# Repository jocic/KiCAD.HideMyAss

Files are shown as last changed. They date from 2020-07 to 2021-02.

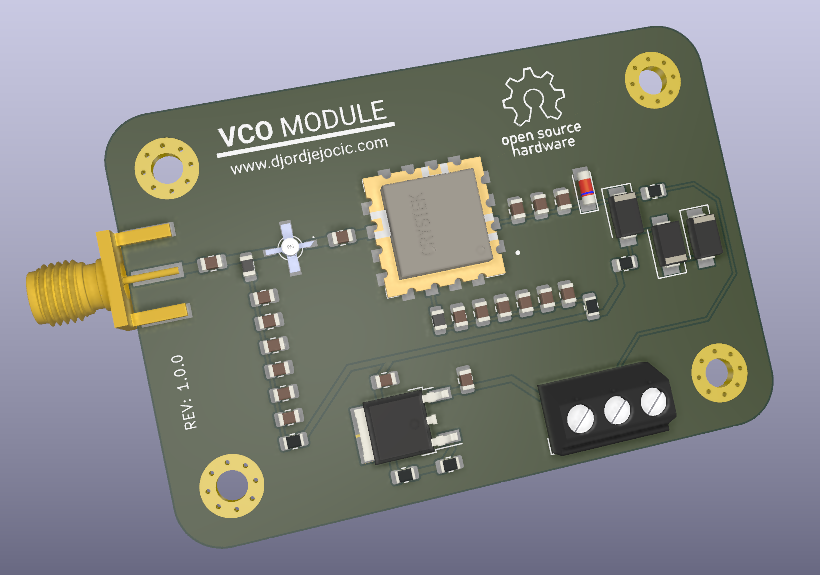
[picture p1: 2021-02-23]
hardware-modular/vco-variants/cvco-general/assets/rendering.png

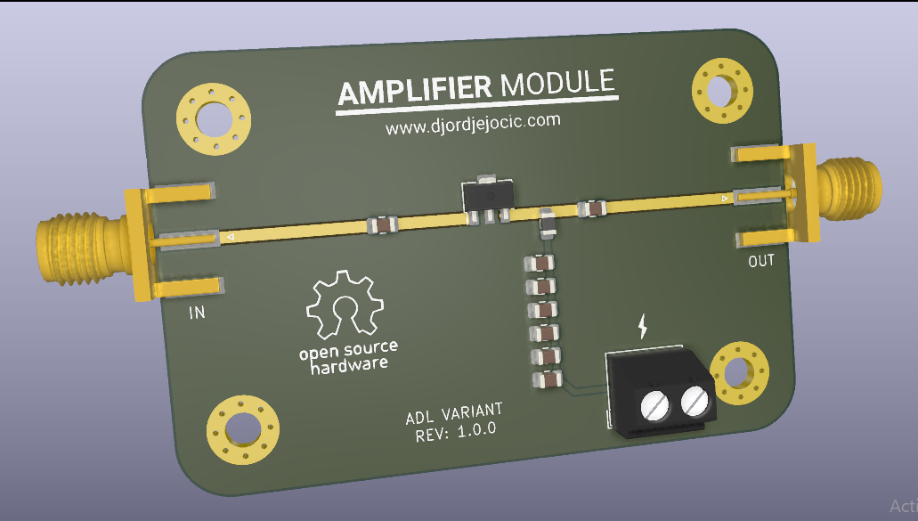
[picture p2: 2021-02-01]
hardware-modular/amplifiers/adl-variant/assets/rendering.png

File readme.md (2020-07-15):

# HideMyAss

**Song of the project:** [Judas Priest - Breaking The Law](https://www.youtube.com/watch?v=L397TWLwrUU)

*  LoJack (173 MHz)
*  SM (925 – 960 MHz)
*  DCS (1805 – 1880 MHz)
*  3G (2100 – 2170 MHz )
*  4G Low (790 – 870 MHz)
*  4G High (2600 – 2690 MHz)
*  5G F1 (450 MHz to 6 GHz)
*  5G F2 (24.25 GHz to 52.6 GHz)
*  WiFi (2400 – 2500 MHz)
*  GPS L1 (1570 – 1580 MHz)
*  GPS L2 (1220 – 1230 MHz)
*  Bluetooth (2.402 GHz - 2.480 GHz)

When finished, device can be ordered directly from my website.

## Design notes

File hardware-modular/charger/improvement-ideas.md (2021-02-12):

- Serial IO port for AT commands (start charging, stop charging, charging status, pause charging, current control, etc.)
- Replace LM741 with a proper comparator
- Use %1 5V voltage reference for the ADC
- Add a boost converter for battery bank that can be used on laptops
- Increase the current up to 1A
- Experiment with LM317 & 0.1A precision voltage regulator for creating precise voltage references ex. 4.2V for the shut off, and 5 for ADC
- Design or find enclosure for the battery bank

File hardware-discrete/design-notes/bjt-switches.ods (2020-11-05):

Device | BD137 |  | Ic | 0.45 | A
Vcc | 7.4 | V | Ib | 0.03 | A
Vbb | 3.5 | V | Rc | 15.33 | Ohm
Vsat | 0.5 | V | Pc | 3.33 | W
Vbe | 1 | V | Rb | 100.00 | Ohm
HFEmin | 25 |  | Pb | 0.09 | W
 |  |  | HFE | 18.00
Topology | Basic |  | Saturated | Yes
Device | 2N3904 |  | Ic | 0.20 | A
Vcc | 7.4 | V | Ib | 0.03 | A
Vbb | 3.5 | V | Rc | 35.50 | Ohm
 |  |  | Pc | 1.48 | W
Vsat | 0.3 | V | Rb | 100.00 | Ohm
 |  |  | Pb | 0.10 | W
Vbe | 0.65 | V | HFE | 7.02
HFEmin | 15 | V
Topology | Basic |  | Saturated | Yes
 |  |  |  |  |  | Basic Topology

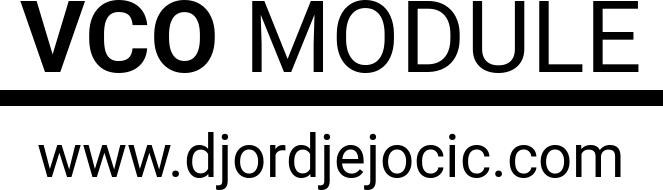
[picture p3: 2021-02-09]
hardware-modular/vco-variants/cvco-general/assets/label.png

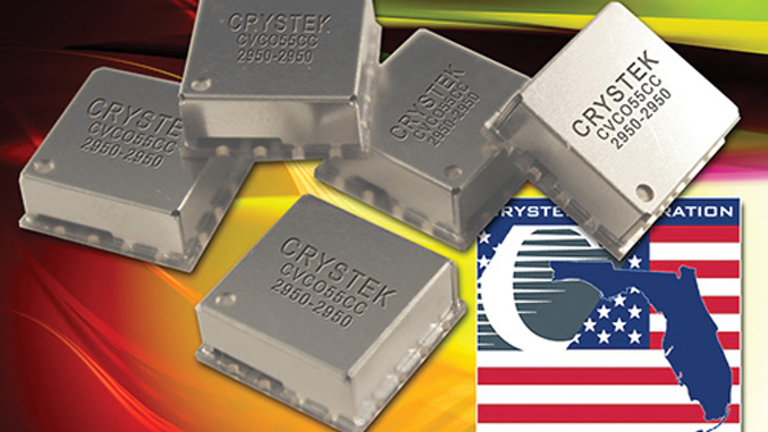
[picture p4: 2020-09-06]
other/datasheet/mwrf_1283_crystek_0.png

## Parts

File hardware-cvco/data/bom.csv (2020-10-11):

Reference | Quantity | Value | Footprint | Datasheet | LCSC Part # | Mouser Part #
BT1 | 1 | 3.7V | CVCO:2-2.54mm-Horizontal-Molex | ~ | C132504
C1 C3 C5 C7 C27 C29 C31 C14 C16 C18 C20 C41 C39 C37 C44 C56 | 16 | 1nF | Capacitor_SMD:C_0805_2012Metric_Pad1.15x1.40mm_HandSolder | ~ | C1791
C10 | 1 | 220pF | Capacitor_SMD:C_0805_2012Metric_Pad1.15x1.40mm_HandSolder | ~ | C1727
C11 | 1 | 100pF | Capacitor_SMD:C_0805_2012Metric_Pad1.15x1.40mm_HandSolder | ~ | C1790
C12 C54 | 2 | 47pF | Capacitor_SMD:C_0805_2012Metric_Pad1.15x1.40mm_HandSolder | ~ | C107118
C13 C22 | 2 | 0.1uF | Capacitor_SMD:C_0805_2012Metric_Pad1.15x1.40mm_HandSolder | ~ | C62912
C2 C4 C6 C8 C28 C30 C32 C15 C17 C19 C21 C42 C40 C38 | 14 | 0.1nF | Capacitor_SMD:C_0805_2012Metric_Pad1.15x1.40mm_HandSolder | ~ | C159771
C33 | 1 | 33pF | Capacitor_SMD:C_0805_2012Metric_Pad1.15x1.40mm_HandSolder | ~ | C157687
C34 | 1 | 27pF | Capacitor_SMD:C_0805_2012Metric_Pad1.15x1.40mm_HandSolder | ~ | C8031
C35 | 1 | 22pF | Capacitor_SMD:C_0805_2012Metric_Pad1.15x1.40mm_HandSolder | ~ | C24658
C43 C36 | 2 | 4.7μF | Capacitor_SMD:C_0805_2012Metric_Pad1.15x1.40mm_HandSolder | ~ | C37818
C51 C24 C50 C48 C26 | 5 | 0.1μF | Capacitor_SMD:C_0805_2012Metric_Pad1.15x1.40mm_HandSolder | ~ | C38141
C52 C53 C49 C23 C47 C46 C45 C25 | 8 | 1μF | Capacitor_SMD:C_0805_2012Metric_Pad1.15x1.40mm_HandSolder | ~ | C215803
C57 C58 C55 | 3 | 10μF | Capacitor_SMD:C_0805_2012Metric_Pad1.15x1.40mm_HandSolder | ~ | C40894
C9 | 1 | 470pF | Capacitor_SMD:C_0805_2012Metric_Pad1.15x1.40mm_HandSolder | ~ | C1743
D1 | 1 | 5.1V | Diode_SMD:D_MiniMELF | ~ | C305343
D10 D12 | 2 | 10V | Diode_SMD:D_MiniMELF | ~ | C398894
D11 | 1 | 1N4002 | Diode_SMD:D_SMA_Handsoldering | ~ | C433393
D3 D2 | 2 | 18V | Diode_SMD:D_MiniMELF | ~ | C268731
D6 | 1 | 16V | Diode_SMD:D_MiniMELF | ~ | C313481
D7 D5 D4 | 3 | 20V | Diode_SMD:D_MiniMELF | ~ | C398899
D8 | 1 | Green | CVCO:2-2.54mm-Horizontal-Molex | ~ | C99763
D9 | 1 | Orange | CVCO:2-2.54mm-Horizontal-Molex | ~ | C99759
F1 | 1 | 1.5A Fast | Fuse:Fuse_1206_3216Metric_Pad1.42x1.75mm_HandSolder | ~ | C151143
J3 J4 J5 J6 J1 J2 J7 | 7 | SMA | CVCO:SMA-Edge | ~ | C530661
J8 | 1 | Pickit 2 | Connector_PinSocket_2.54mm:PinSocket_1x03_P2.54mm_Horizontal | ~ | C49257
J9 | 1 | DC | Connector_Wire:SolderWirePad_1x02_P3.81mm_Drill1mm | ~
L1 | 1 | 10μH | Capacitor_SMD:C_0805_2012Metric_Pad1.15x1.40mm_HandSolder | ~ | C1046
Q1 | 1 | AOD403 | Package_TO_SOT_SMD:TO-252-2 | https://datasheet.lcsc.com/szlcsc/1811071514_Alpha-Omega-Semicon-AOD403_C28969.pdf | C28969
Q2 | 1 | MBT2222 | Package_TO_SOT_SMD:SOT-23 | https://datasheet.lcsc.com/szlcsc/1809272022_ON-Semiconductor-MMBT2222ALT1G_C82460.pdf | C82460
R1 R17 R35 R9 R6 R21 R20 R19 R4 R7 R3 R2 R10 R11 R12 R25 R26 R27 | 18 | 1k | Resistor_SMD:R_0805_2012Metric_Pad1.15x1.40mm_HandSolder | ~ | C17513
R13 R28 | 2 | 220 | Resistor_SMD:R_0805_2012Metric_Pad1.15x1.40mm_HandSolder |  | C17557
R14 | 1 | 560 | Resistor_SMD:R_0805_2012Metric_Pad1.15x1.40mm_HandSolder |  | C28636
R16 R30 | 2 | 470 | Resistor_SMD:R_0805_2012Metric_Pad1.15x1.40mm_HandSolder |  | C17710
R18 R39 R23 R54 R53 | 5 | 2k | Resistor_SMD:R_0805_2012Metric_Pad1.15x1.40mm_HandSolder | ~ | C17604
R24 R8 | 2 | 1.4k | Resistor_SMD:R_0805_2012Metric_Pad1.15x1.40mm_HandSolder | ~ | C17388
R29 | 1 | 270 | Resistor_SMD:R_0805_2012Metric_Pad1.15x1.40mm_HandSolder |  | C17590
R31 | 1 | 3M | Resistor_SMD:R_0805_2012Metric_Pad1.15x1.40mm_HandSolder | ~ | C17662
R34 R15 | 2 | 680 | Resistor_SMD:R_0805_2012Metric_Pad1.15x1.40mm_HandSolder | ~ | C17798
R36 R33 | 2 | 120 | Resistor_SMD:R_0805_2012Metric_Pad1.15x1.40mm_HandSolder | ~ | C111022
R40 | 1 | 3.3k | Resistor_SMD:R_0805_2012Metric_Pad1.15x1.40mm_HandSolder | ~ | C26010
R41 R51 R52 | 3 | 15k | Resistor_SMD:R_0805_2012Metric_Pad1.15x1.40mm_HandSolder | ~ | C17475
R42 R37 | 2 | 4.7k | Resistor_SMD:R_0805_2012Metric_Pad1.15x1.40mm_HandSolder | ~ | C47010
R44 | 1 | 27k | Resistor_SMD:R_0805_2012Metric_Pad1.15x1.40mm_HandSolder | ~ | C17593
R45 | 1 | 6.8k | Resistor_SMD:R_0805_2012Metric_Pad1.15x1.40mm_HandSolder | ~ | C17772
R48 R32 R43 | 3 | 100k | Resistor_SMD:R_0805_2012Metric_Pad1.15x1.40mm_HandSolder | ~ | C55868
R49 R46 R38 R47 | 4 | 10k | Resistor_SMD:R_0805_2012Metric_Pad1.15x1.40mm_HandSolder | ~ | C55866
R5 R22 | 2 | 3.9k | Resistor_SMD:R_0805_2012Metric_Pad1.15x1.40mm_HandSolder | ~ | C17614
R50 | 1 | 10 | Resistor_SMD:R_0805_2012Metric_Pad1.15x1.40mm_HandSolder | ~
R55 | 1 | 150 | Resistor_SMD:R_0805_2012Metric_Pad1.15x1.40mm_HandSolder | ~ | C17513
R56 | 1 | 480 | Resistor_SMD:R_0805_2012Metric_Pad1.15x1.40mm_HandSolder | ~ | C55866
R57 | 1 | 100 | Resistor_SMD:R_0805_2012Metric_Pad1.15x1.40mm_HandSolder | ~ | C17513
SW1 | 1 | On/Off | CVCO:2-2.54mm-Horizontal-Molex |  | C505003
TH1 | 1 | 10k | CVCO:2-2.54mm-Horizontal-Molex | ~ | C13879
U1 | 1 | 74LS07 | Package_SO:SOIC-14_3.9x8.7mm_P1.27mm | http://www.ti.com/lit/gpn/sn74LS06 | C513513
U10 | 1 | TPS61046 | Package_TO_SOT_SMD:SOT-23-6_Handsoldering | https://datasheet.lcsc.com/szlcsc/2001152032_Texas-Instruments-TLV61046ADBVR_C464815.pdf | C464815
U11 | 1 | BQ21040 | Package_TO_SOT_SMD:SOT-23-6 | https://datasheet.lcsc.com/szlcsc/1810101925_Texas-Instruments-BQ21040DBVR_C202311.pdf | C202311
U12 | 1 | LM324 | Package_SO:SOIC-14_3.9x8.7mm_P1.27mm | http://www.ti.com/lit/ds/symlink/lm2902-n.pdf | C71035
U13 | 1 | LM317DCYR | Package_TO_SOT_SMD:SOT-223-3_TabPin2 | https://datasheet.lcsc.com/szlcsc/1811032110_Texas-Instruments-LM317DCYR_C51466.pdf | C51466
U14 | 1 | LM386 | Package_SO:SO-8_5.3x6.2mm_P1.27mm | http://www.ti.com/lit/ds/symlink/lm386.pdf
U4 U5 U7 U8 U2 U3 U9 | 7 | NLB-310-T1 | CVCO:Micro-X-4 |  |  | 772-NLB-310
U6 | 1 | PIC12F675-ISN | Package_SO:SOIC-8_3.9x4.9mm_P1.27mm | http://ww1.microchip.com/downloads/en/DeviceDoc/41190G.pdf | C96100
Y1 | 1 | CVCO55CW-0100-0200 | CVCO:CVCO55 | https://www.crystek.com/microwave/admin/webapps/welcome/files/vco/CVCO55CW-0100-0200.pdf |  | 549-CV55CW0100-0200
Y2 | 1 | CVCO55CW-0200-0500 | CVCO:CVCO55 | https://www.crystek.com/microwave/admin/webapps/welcome/files/vco/CVCO55CW-0200-0500.pdf |  | 549-CV55CW0200-0500
Y3 | 1 | CV55CW500-1000 | CVCO:CVCO55 | https://www.crystek.com/microwave/admin/webapps/welcome/files/vco/CVCO55CW-0500-1000.pdf |  | 549-CV55CW500-1000
Y4 | 1 | CVCO55CW-1000-2000 | CVCO:CVCO55 | https://www.crystek.com/microwave/admin/webapps/welcome/files/vco/CVCO55CW-1000-2000.pdf |  | 549-CV55CW1000-2000
Y5 | 1 | CV55BE1600-3200 | CVCO:CVCO55 | https://www.crystek.com/microwave/admin/webapps/welcome/files/vco/CVCO55CW-1600-3200.pdf |  | 549-CV55BE1600-3200
Y6 | 1 | CVCO55CC-3180-3710 | CVCO:CVCO55 | https://www.crystek.com/microwave/admin/webapps/welcome/files/vco/CVCO55CC-3180-3710.pdf |  | 549-CVCO55CC31803710
Y7 | 1 | CVCO55CW-3500-4500 | CVCO:CVCO55 | https://www.crystek.com/microwave/admin/webapps/welcome/files/vco/CVCO55CW-3500-4500.pdf |  | 549-CVC55CW3500-4500

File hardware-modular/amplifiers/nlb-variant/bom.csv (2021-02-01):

Reference | Quantity | Value | Footprint | Datasheet
C1 C2 | 2 | 1μF | Capacitor_SMD:C_0805_2012Metric | ~
C3 C4 | 2 | 1.2nF | Capacitor_SMD:C_0805_2012Metric | ~
C5 C6 | 2 | 68pF | Capacitor_SMD:C_0805_2012Metric | ~
C7 C8 | 2 | 0.1μF | Capacitor_SMD:C_0805_2012Metric | ~
H1 H2 H3 H4 | 4 | Mounting Pad | MountingHole:MountingHole_3.2mm_M3_Pad_Via | ~
J1 | 1 | DC_IN | TerminalBlock_4Ucon:TerminalBlock_4Ucon_1x02_P3.50mm_Horizontal | ~
J2 | 1 | RF_IN | Connector_Coaxial:SMA_Amphenol_132289_EdgeMount | ~
J3 | 1 | RF_OUT | Connector_Coaxial:SMA_Amphenol_132289_EdgeMount | ~
L1 | 1 | 470μH | Inductor_SMD:L_0805_2012Metric | ~
R1 | 1 | 300 | Resistor_SMD:R_0805_2012Metric | ~
U1 | 1 | NLB-310 | CVCO:Micro-X-4

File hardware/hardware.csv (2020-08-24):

Value | Footprint | Designator | Quantity | LCSC Part #
USBLC6-2 | SOT-23-6 | U3 | 1 | C7519
PIC18F45K50_QFP | TQFP-44 | U5 | 1 | C219580
100nF | 0603 | C3 | 1 | C14663
LM317A | TO-252-2 | U4 | 1 | C75510
0.1μF | 0603 | C5 | 1 | C14663
1μF | 0603 | C13 | 1 | C15849
1k | 0603 | R7 | 1 | C21190
1.5k | 0603 | R8 | 1 | C22843
M7 | Diotec | D4 | 1 | C95872
10μF | 0603 | C12 | 1 | C19702
DW01+G | TSOT-23-6 | U1 | 1 | C14213
100 | 0603 | R4 | 1 | C7250
0.1μF | 0603 | C4 | 1 | C14663
TP4056 | SSOP-8_2 | U2 | 1 | C16581
FS8205 | TSOT-23-6 | Q1 | 1 | C32254
1k | 0603 | R6 | 1 | C21190
180 | 0603 | R1 | 1 | C25810
ZMM5V1 | MiniMELF | D2 | 1 | C8061
GHC-YR | 0603 | D1 | 1 | C72043
BHC-ZL | 0603 | D3 | 1 | C72041
68 | 0603 | R2 | 1 | C13415
68 | 0603 | R3 | 1 | C13415
10μF | 0603 | C1 | 1 | C19702
2k | 0603 | R5 | 1 | C22975
10μF | 0603 | C2 | 1 | C19702
10μF | 0603 | C6 | 1 | C19702
0.1μF | 0603 | C7 | 1 | C14663
0.1μF | 0603 | C8 | 1 | C14663
10μF | 0603 | C11 | 1 | C19702
0.1μF | 0603 | C10 | 1 | C14663
0.1μF | 0603 | C9 | 1 | C14663
480 | 0603 | R10 | 1 | C17480
10k | 0603 | R9 | 1 | C25804
0.1μF | 0603 | C14 | 1 | C14663

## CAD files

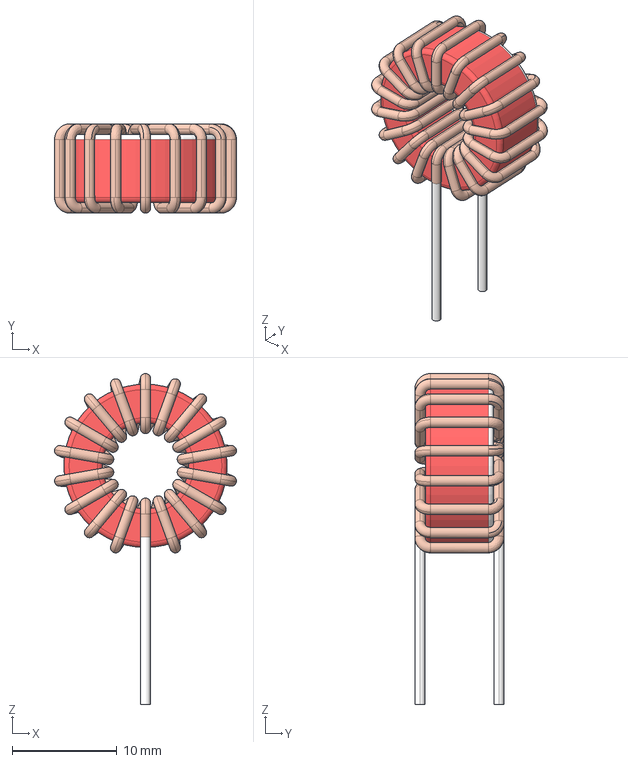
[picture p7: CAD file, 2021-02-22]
other/3d-models/toroidal-horizontal.step
17.4 x 8.54 x 31.6 mm

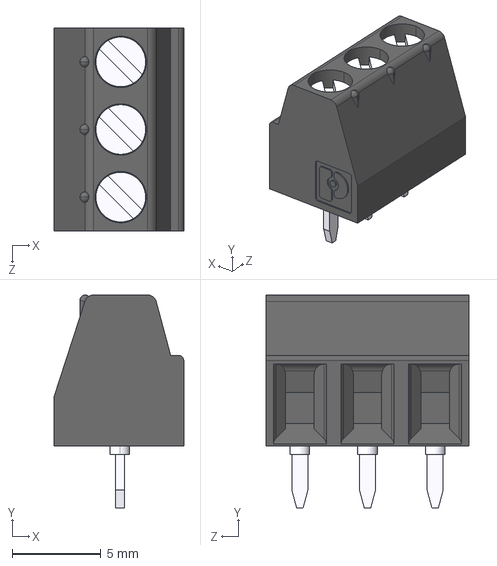
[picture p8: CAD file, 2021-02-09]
other/3d-models/3-3.84-terminal-block.step
7.30 x 12.0 x 11.4 mm

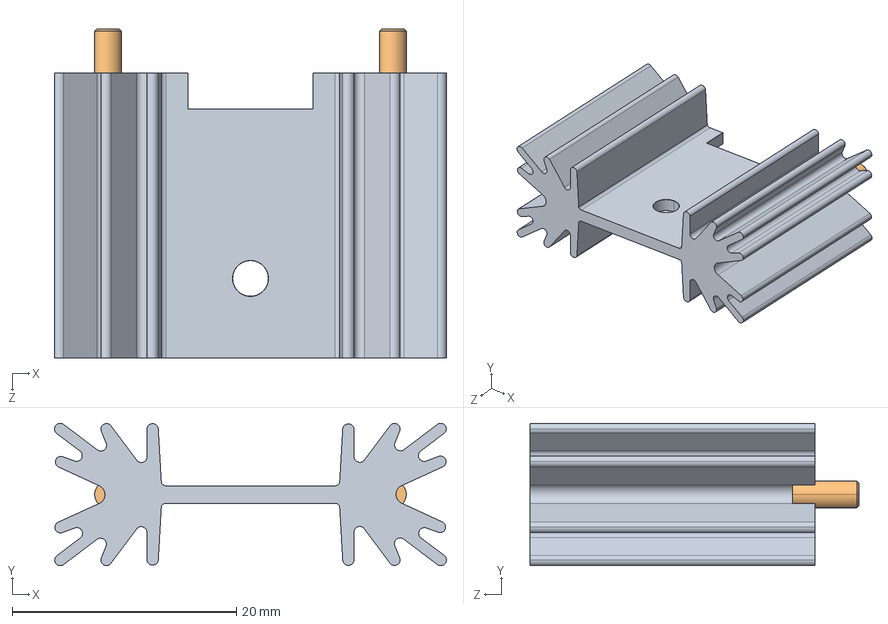
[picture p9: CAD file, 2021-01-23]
other/3d-models/to-220-heatsink.step
34.9 x 12.7 x 29.4 mm

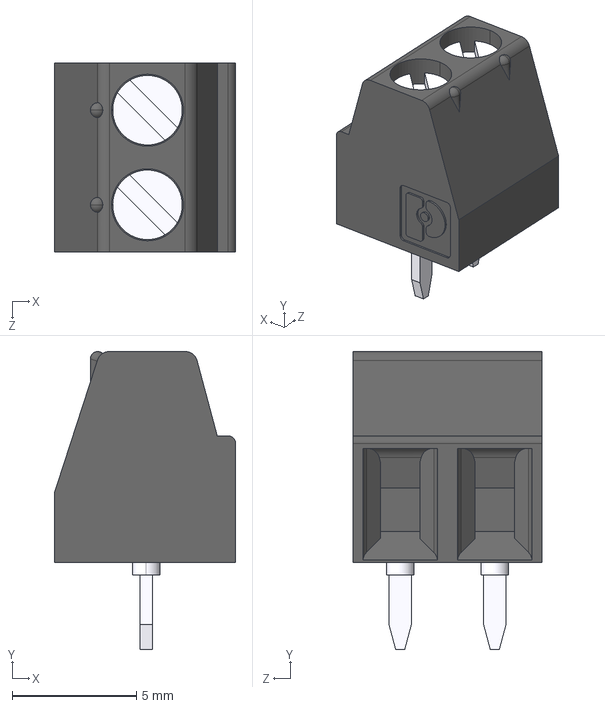
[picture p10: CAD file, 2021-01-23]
other/3d-models/2-3.84-terminal-block.step
7.30 x 12.0 x 7.62 mm

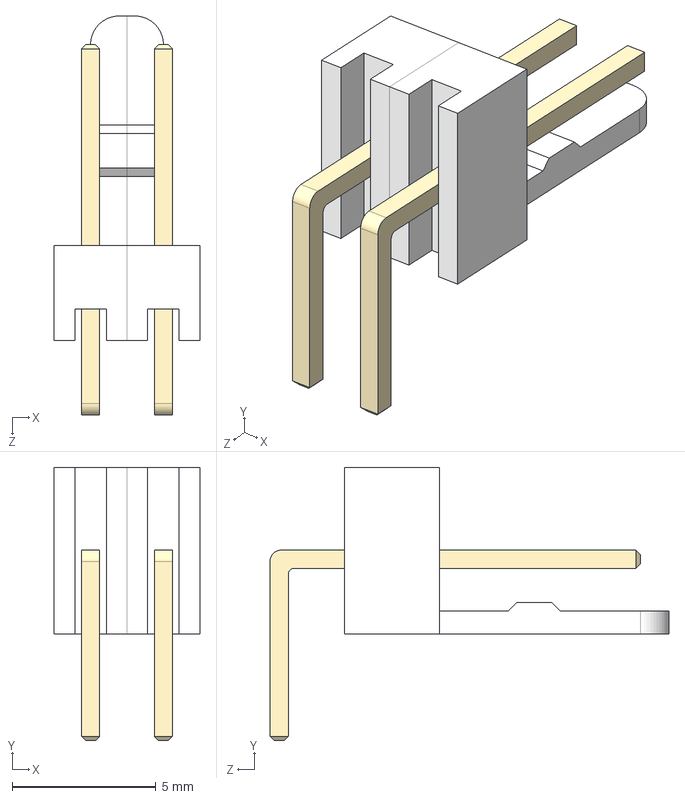
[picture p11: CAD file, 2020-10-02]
other/3d-models/2-2.54mm-horizontal-molex.step
5.08 x 9.52 x 13.9 mm
Molex_Stecker_90Grad_rechts
Molex_Stecker_90Grad_links

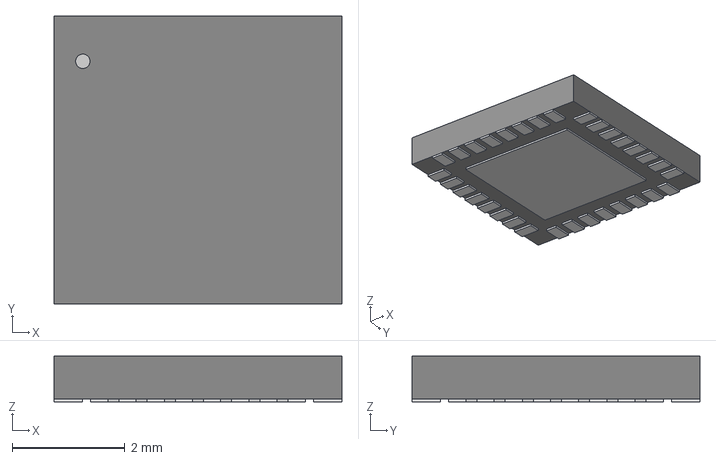
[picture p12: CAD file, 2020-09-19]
other/3d-models/tqfn-32.step
5.11 x 5.11 x 0.815 mm

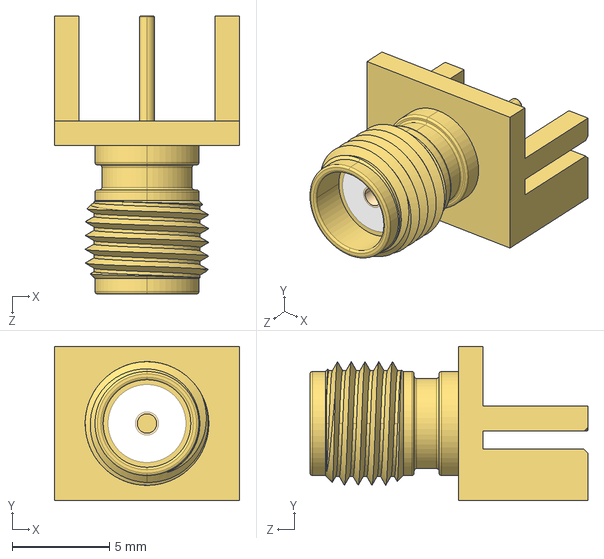
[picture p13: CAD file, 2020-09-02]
other/3d-models/sma-edge.step
9.52 x 7.92 x 14.3 mm

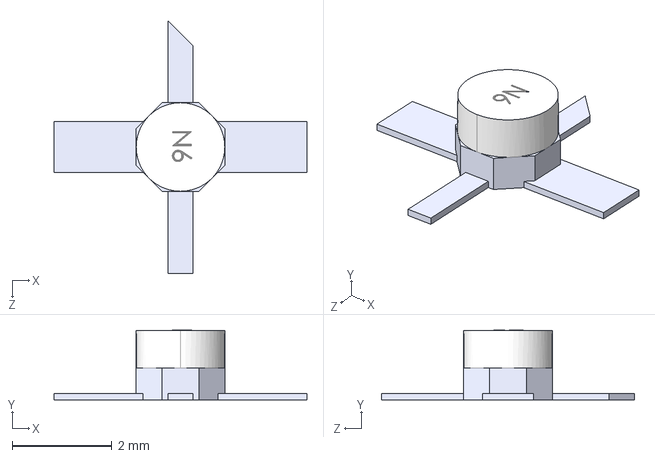
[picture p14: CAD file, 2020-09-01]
other/3d-models/micro-x-4.step
5.08 x 1.40 x 5.08 mm

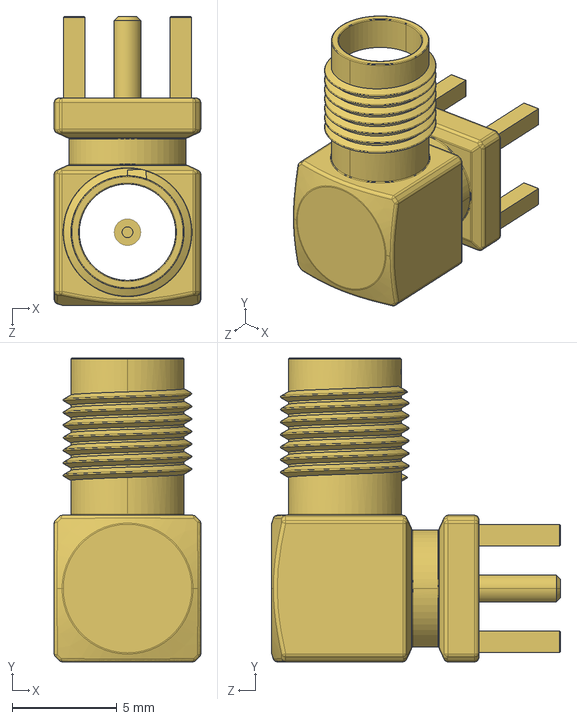
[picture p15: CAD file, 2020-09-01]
other/3d-models/sma-angled.step
7.00 x 14.5 x 13.8 mm

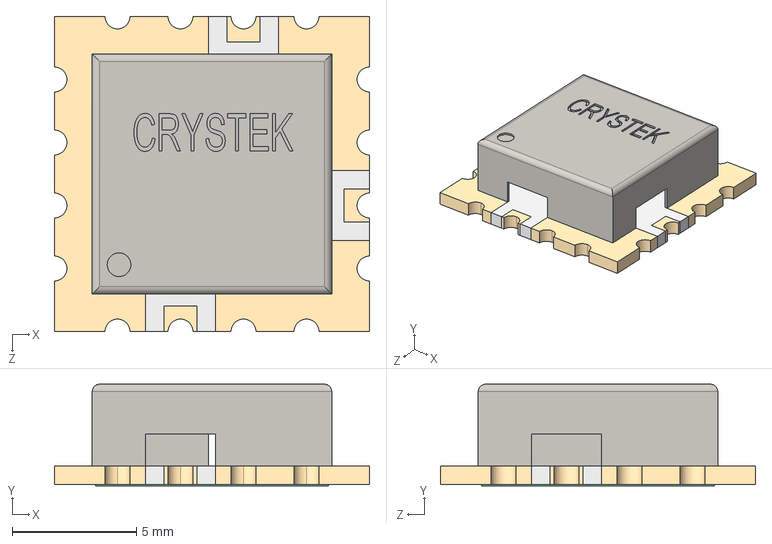
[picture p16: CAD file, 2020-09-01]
other/3d-models/cvco55.step
12.7 x 4.10 x 12.7 mm

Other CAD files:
software-discrete/dist/main.obj
software-discrete/dist/startup.obj

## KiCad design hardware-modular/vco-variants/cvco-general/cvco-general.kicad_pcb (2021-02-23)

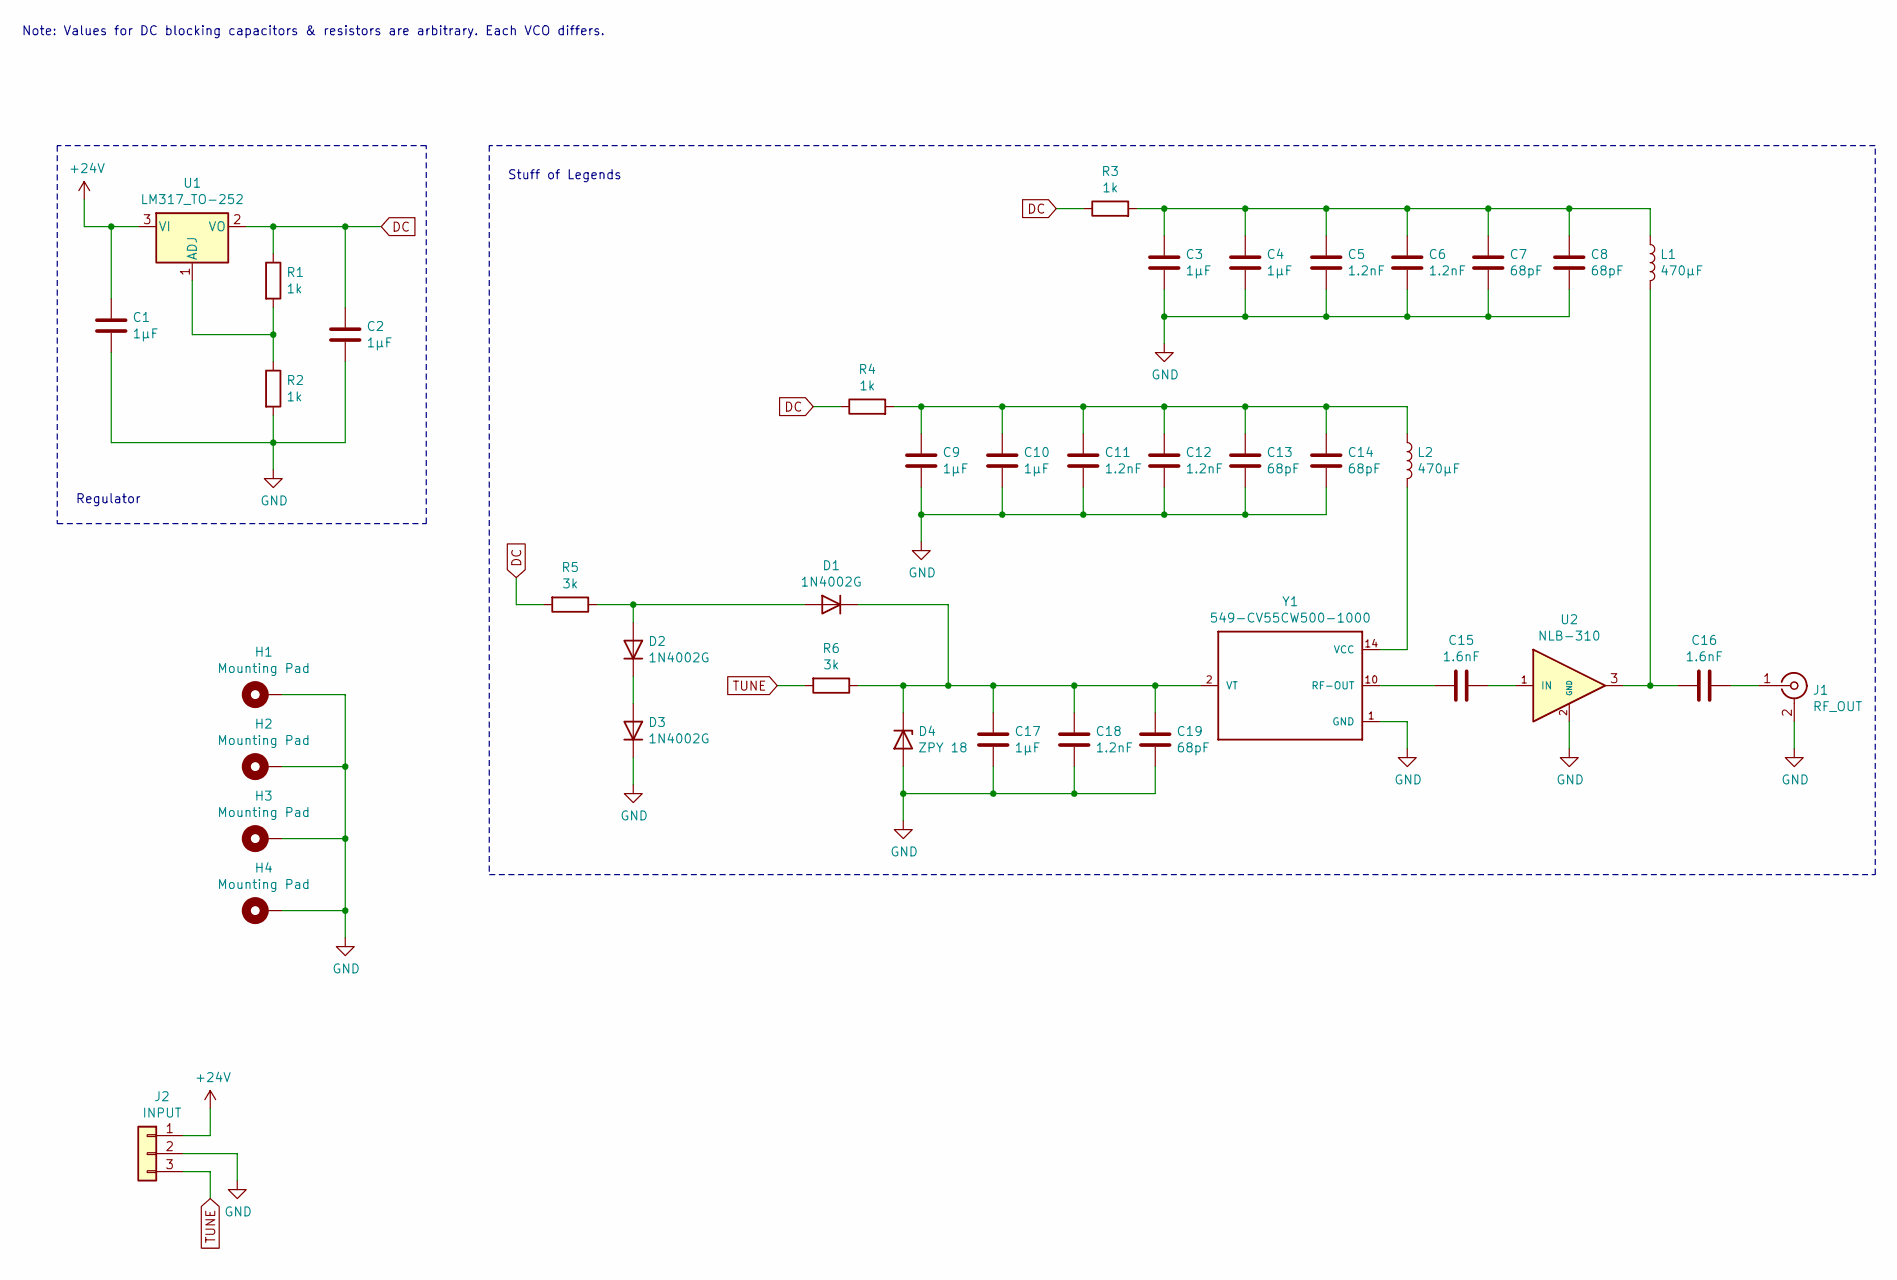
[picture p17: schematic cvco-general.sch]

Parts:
C1, C2, C3, C4, C9, C10, C17: 1μF; C_0805_2012Metric
C5, C6, C11, C12, C18: 1.2nF; C_0805_2012Metric
C7, C8, C13, C14, C19: 68pF; C_0805_2012Metric
C15, C16: 1.6nF; C_0805_2012Metric
D1, D2, D3: 1N4002G; D_SMA
D4: ZPY 18; D_MiniMELF
H1, H2, H3, H4: Mounting Pad; MountingHole_3.2mm_M3_Pad_Via
J1: RF_OUT; SMA_Amphenol_132289_EdgeMount
J2: INPUT; TerminalBlock_4Ucon_1x03_P3.50mm_Horizontal
L1, L2: 470μF; L_0805_2012Metric
R1, R2, R3, R4: 1k; R_0805_2012Metric
R5, R6: 3k; R_0805_2012Metric
U1: LM317_TO-252; TO-252-2
U2: NLB-310; Micro-X-4
Y1: 549-CV55CW500-1000; CVCO55

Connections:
+24V: C1.1, J2.1, U1.3 (VI)
DC: C2.1, R1.1, R3.1, R4.1, R5.2, U1.2 (VO)
GND: C1.2, C2.2, C3.2, C4.2, C5.2, C6.2, C7.2, C8.2, C9.2, C10.2, C11.2, C12.2, C13.2, C14.2, C17.2, C18.2, C19.2, D3.1 (K), D4.2 (A), H1.1, H2.1, H3.1, H4.1, J1.2 (Ext), J2.2, R2.2, U2.2 (GND), U2.4 (GND), Y1.1 (GND), Y1.3 (GND), Y1.4 (GND), Y1.5 (GND), Y1.6 (GND), Y1.7 (GND), Y1.8 (GND), Y1.9 (GND), Y1.11 (GND), Y1.12 (GND), Y1.13 (GND), Y1.15 (GND), Y1.16 (GND)
unnamed: C3.1, C4.1, C5.1, C6.1, C7.1, C8.1, L1.1, R3.2
unnamed: C9.1, C10.1, C11.1, C12.1, C13.1, C14.1, L2.1, R4.2
unnamed: C15.1, U2.1 (IN)
unnamed: C15.2, Y1.10 (RF-OUT)
unnamed: C16.1, J1.1 (In)
unnamed: C16.2, L1.2, U2.3
unnamed: C17.1, C18.1, C19.1, D1.1 (K), D4.1 (K), R6.1, Y1.2 (VT)
unnamed: D1.2 (A), D2.2 (A), R5.1
unnamed: D2.1 (K), D3.2 (A)
unnamed: L2.2, Y1.14 (VCC)
unnamed: R1.2, R2.1, U1.1 (ADJ)
TUNE: J2.3, R6.2

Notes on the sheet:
Regulator
Stuff of Legends
Note: Values for DC blocking capacitors & resistors are arbitrary. Each VCO differs.

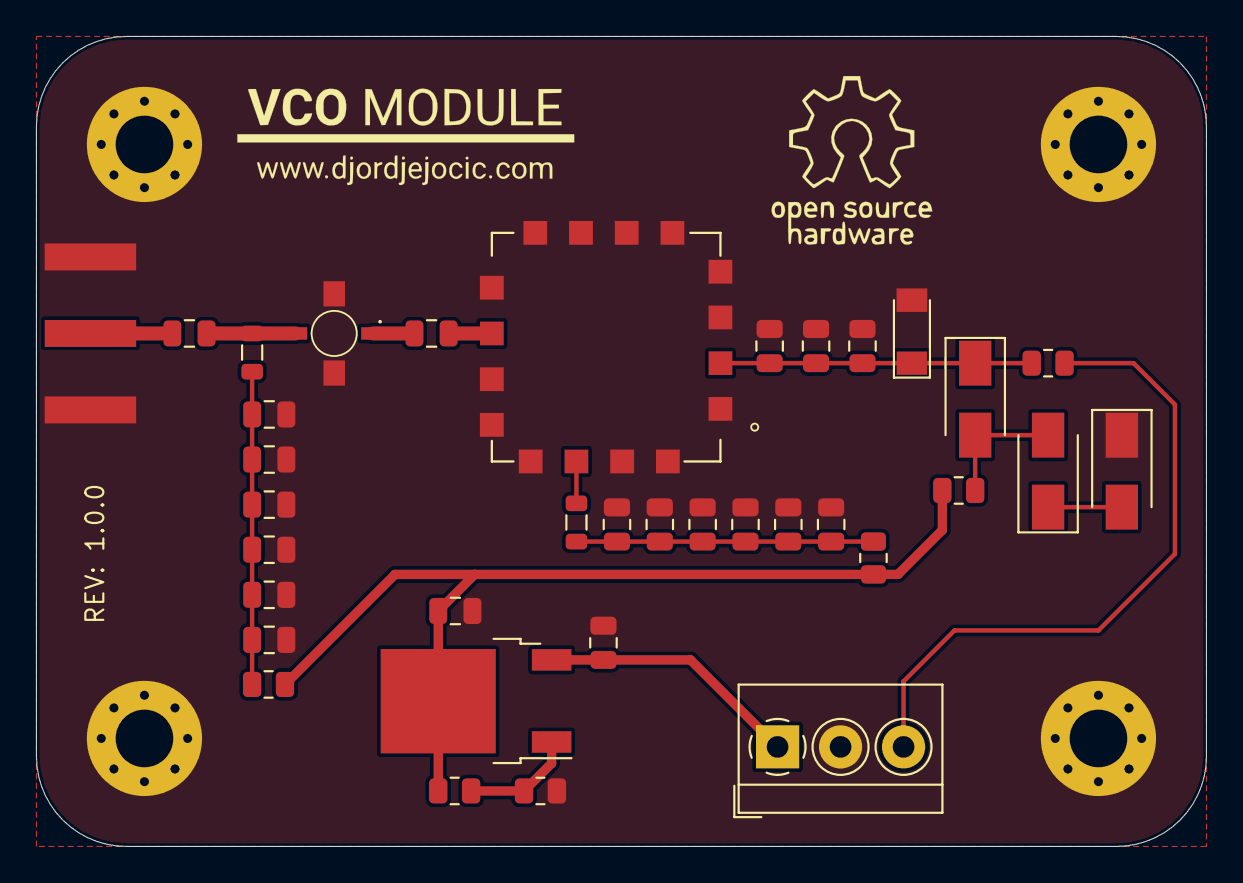
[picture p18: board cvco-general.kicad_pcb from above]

Board: 2 copper layers, 65.0 x 45.0 mm, 40 parts (0 on the bottom side), 15 nets.

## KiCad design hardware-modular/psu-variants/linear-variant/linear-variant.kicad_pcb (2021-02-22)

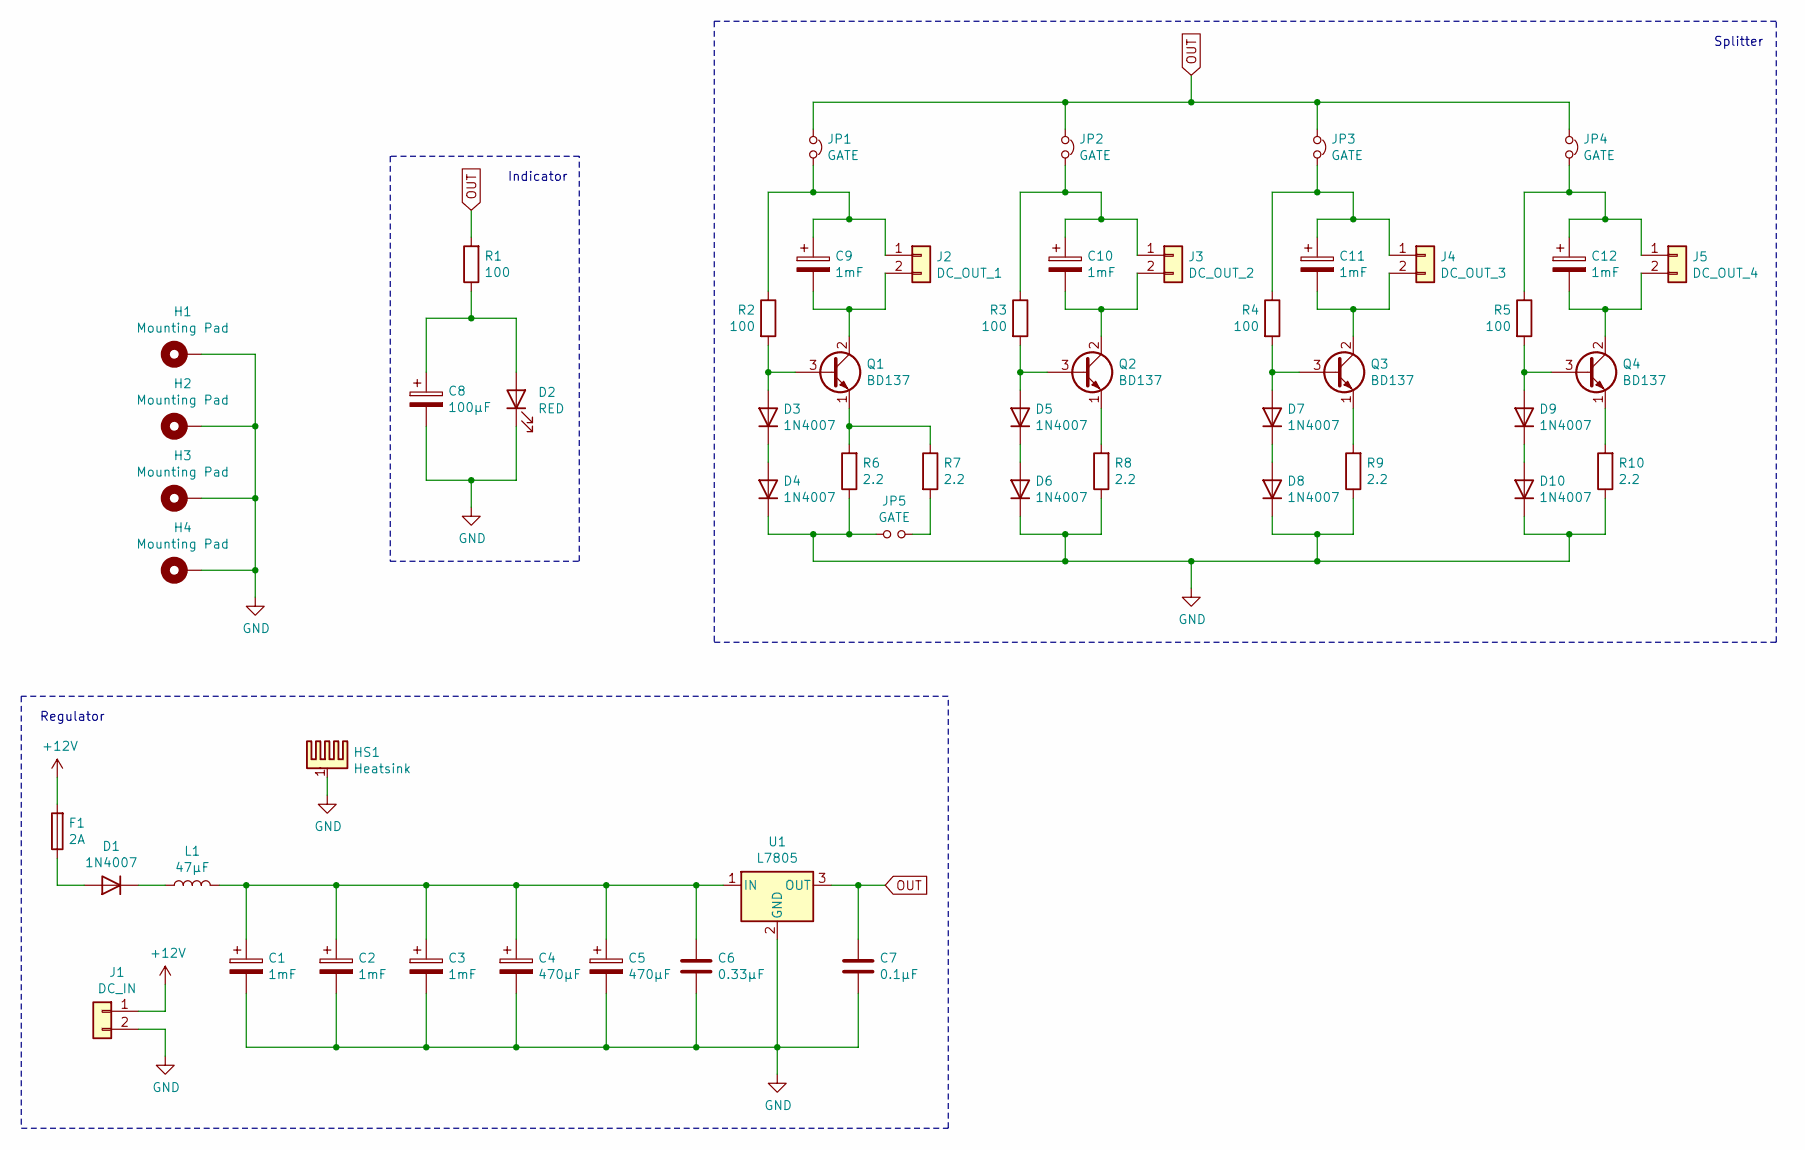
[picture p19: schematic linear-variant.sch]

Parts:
C1, C2, C3: 1mF; CP_Radial_D10.0mm_P5.00mm
C4, C5: 470µF; CP_Radial_D10.0mm_P5.00mm
C6: 0.33µF; C_Disc_D3.0mm_W1.6mm_P2.50mm
C7: 0.1µF; C_Disc_D3.0mm_W1.6mm_P2.50mm
C8: 100µF; CP_Radial_D5.0mm_P2.00mm
C9, C10, C11, C12: 1mF; CP_Radial_D8.0mm_P3.50mm
D1: 1N4007; D_DO-41_SOD81_P10.16mm_Horizontal
D2: RED; Molex_KK-254_AE-6410-02A_1x02_P2.54mm_Vertical
D3, D4, D5, D6, D7, D8, D9, D10: 1N4007; D_DO-41_SOD81_P2.54mm_Vertical_AnodeUp
F1: 2A; Fuseholder_Cylinder-5x20mm_Stelvio-Kontek_PTF78_Horizontal_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
H1, H2, H3, H4: Mounting Pad; MountingHole_3.2mm_M3_Pad_Via
HS1: Heatsink; Heatsink_Fischer_SK104-STCB_35x13mm__2xDrill3.5mm_ScrewM3
J1: DC_IN; TerminalBlock_4Ucon_1x02_P3.50mm_Horizontal
J2: DC_OUT_1; TerminalBlock_4Ucon_1x02_P3.50mm_Horizontal
J3: DC_OUT_2; TerminalBlock_4Ucon_1x02_P3.50mm_Horizontal
J4: DC_OUT_3; TerminalBlock_4Ucon_1x02_P3.50mm_Horizontal
J5: DC_OUT_4; TerminalBlock_4Ucon_1x02_P3.50mm_Horizontal
JP1, JP2, JP3, JP4, JP5: GATE; PinHeader_1x02_P2.54mm_Vertical
L1: 47µF; L_Toroid_Vertical_L16.0mm_W8.0mm_P7.62mm
Q1, Q2, Q3, Q4: BD137; TO-126-3_Vertical
R1, R2, R3, R4, R5: 100; R_Axial_DIN0207_L6.3mm_D2.5mm_P10.16mm_Horizontal
R6, R7: 2.2; R_Axial_DIN0309_L9.0mm_D3.2mm_P12.70mm_Horizontal
R8, R9, R10: 2.2; R_Axial_DIN0207_L6.3mm_D2.5mm_P10.16mm_Horizontal
U1: L7805; TO-220-3_Vertical

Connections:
+12V: F1.2, J1.1
GND: C1.2, C2.2, C3.2, C4.2, C5.2, C6.2, C7.2, C8.2, D2.1 (K), D4.1 (K), D6.1 (K), D8.1 (K), D10.1 (K), H1.1, H2.1, H3.1, H4.1, HS1.1, J1.2, JP5.1, R6.1, R8.1, R9.1, R10.1, U1.2 (GND)
unnamed: C1.1, C2.1, C3.1, C4.1, C5.1, C6.1, L1.2, U1.1 (IN)
unnamed: C8.1, D2.2 (A), R1.1
unnamed: C9.1, J2.1, JP1.2, R2.1
unnamed: C9.2, J2.2, Q1.2 (C)
unnamed: C10.1, J3.1, JP2.2, R3.1
unnamed: C10.2, J3.2, Q2.2 (C)
unnamed: C11.1, J4.1, JP3.2, R4.1
unnamed: C11.2, J4.2, Q3.2 (C)
unnamed: C12.1, J5.1, JP4.2, R5.1
unnamed: C12.2, J5.2, Q4.2 (C)
unnamed: D1.1 (K), L1.1
unnamed: D1.2 (A), F1.1
unnamed: D3.1 (K), D4.2 (A)
unnamed: D3.2 (A), Q1.3 (B), R2.2
unnamed: D5.1 (K), D6.2 (A)
unnamed: D5.2 (A), Q2.3 (B), R3.2
unnamed: D7.1 (K), D8.2 (A)
unnamed: D7.2 (A), Q3.3 (B), R4.2
unnamed: D9.2 (A), Q4.3 (B), R5.2
unnamed: D9.1 (K), D10.2 (A)
unnamed: JP5.2, R7.2
unnamed: Q1.1 (E), R6.2, R7.1
unnamed: Q2.1 (E), R8.2
unnamed: Q3.1 (E), R9.2
unnamed: Q4.1 (E), R10.2
OUT: C7.1, JP1.1, JP2.1, JP3.1, JP4.1, R1.2, U1.3 (OUT)

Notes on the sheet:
Regulator
Splitter
Indicator

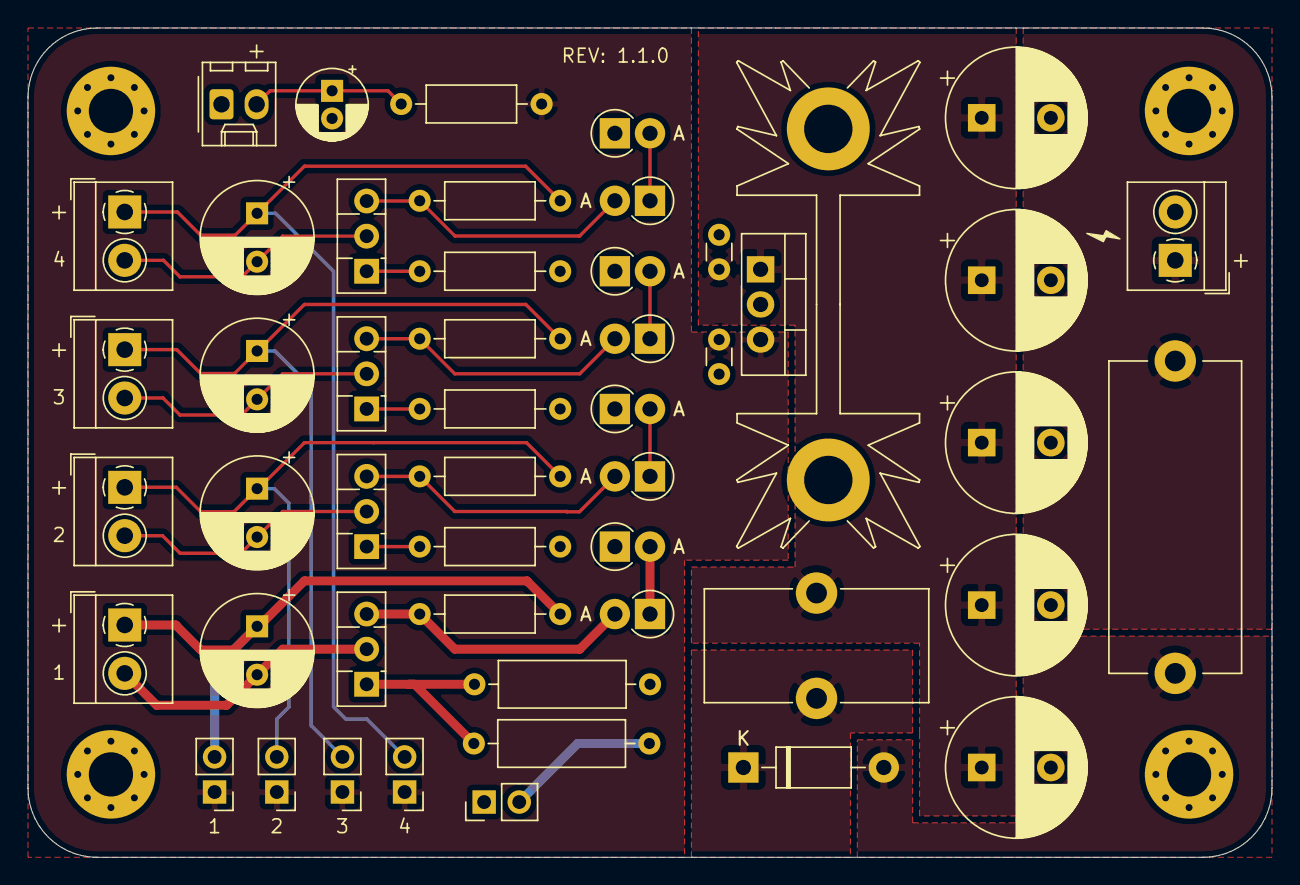
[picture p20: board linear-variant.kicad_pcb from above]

Board: 2 copper layers, 90.0 x 60.0 mm, 54 parts (0 on the bottom side), 28 nets.

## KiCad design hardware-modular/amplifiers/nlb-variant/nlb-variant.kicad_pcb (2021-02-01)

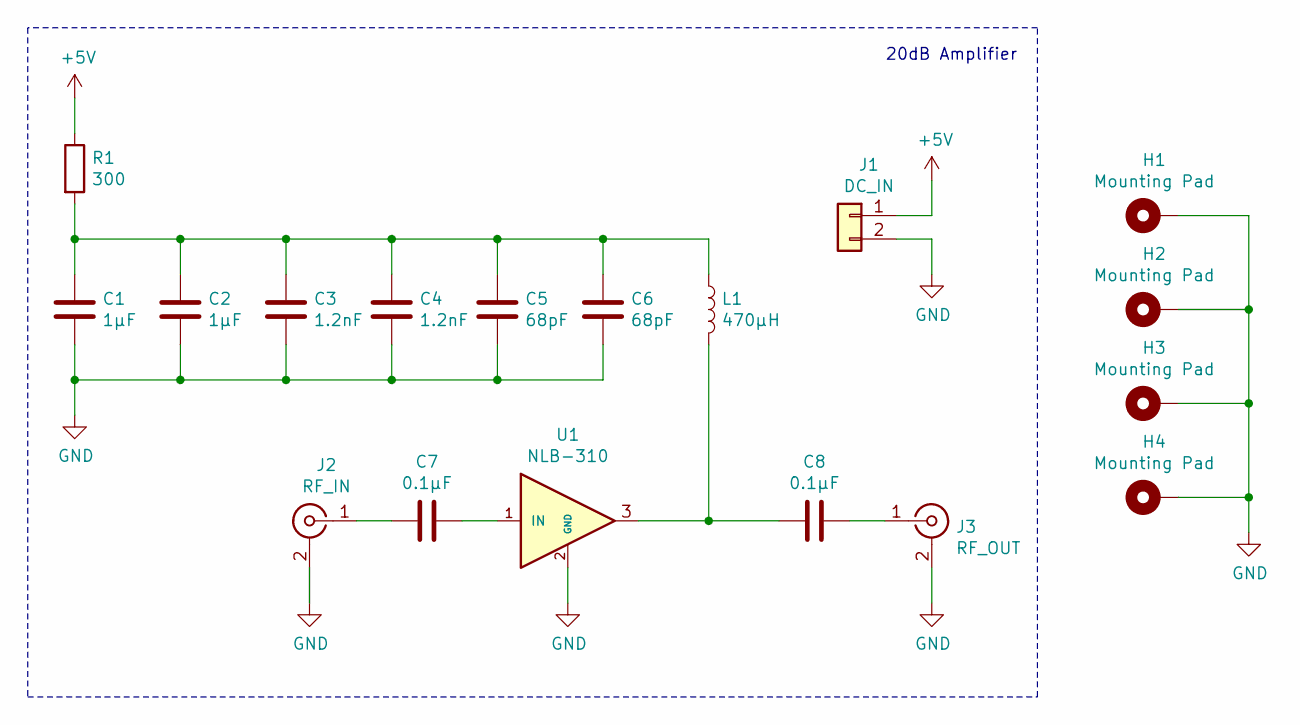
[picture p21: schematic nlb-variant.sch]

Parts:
C1, C2: 1μF; C_0805_2012Metric
C3, C4: 1.2nF; C_0805_2012Metric
C5, C6: 68pF; C_0805_2012Metric
C7, C8: 0.1μF; C_0805_2012Metric
H1, H2, H3, H4: Mounting Pad; MountingHole_3.2mm_M3_Pad_Via
J1: DC_IN; TerminalBlock_4Ucon_1x02_P3.50mm_Horizontal
J2: RF_IN; SMA_Amphenol_132289_EdgeMount
J3: RF_OUT; SMA_Amphenol_132289_EdgeMount
L1: 470μH; L_0805_2012Metric
R1: 300; R_0805_2012Metric
U1: NLB-310; Micro-X-4

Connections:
+5V: J1.1, R1.1
GND: C1.2, C2.2, C3.2, C4.2, C5.2, C6.2, H1.1, H2.1, H3.1, H4.1, J1.2, J2.2 (Ext), J3.2 (Ext), U1.2 (GND), U1.4 (GND)
unnamed: C1.1, C2.1, C3.1, C4.1, C5.1, C6.1, L1.1, R1.2
unnamed: C7.1, J2.1 (In)
unnamed: C7.2, U1.1 (IN)
unnamed: C8.1, L1.2, U1.3
unnamed: C8.2, J3.1 (In)

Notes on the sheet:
20dB Amplifier

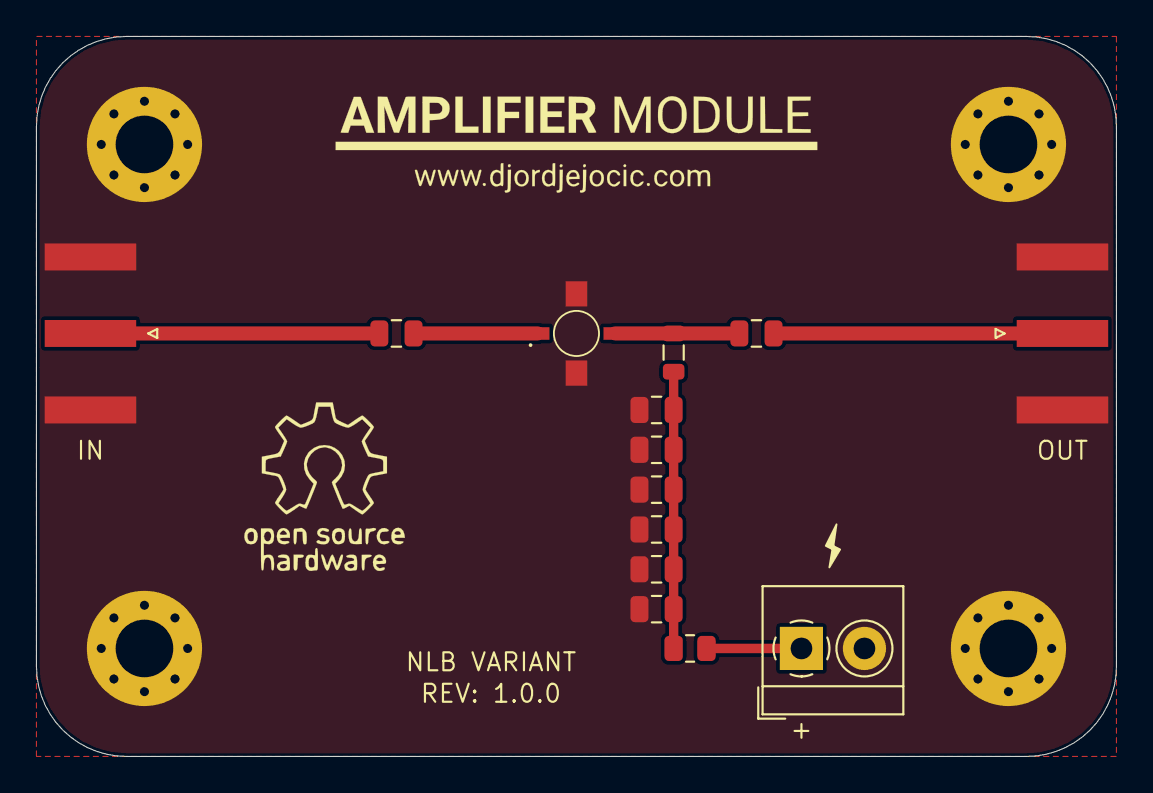
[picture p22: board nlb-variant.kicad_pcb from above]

Board: 2 copper layers, 60.0 x 40.0 mm, 18 parts (0 on the bottom side), 7 nets.

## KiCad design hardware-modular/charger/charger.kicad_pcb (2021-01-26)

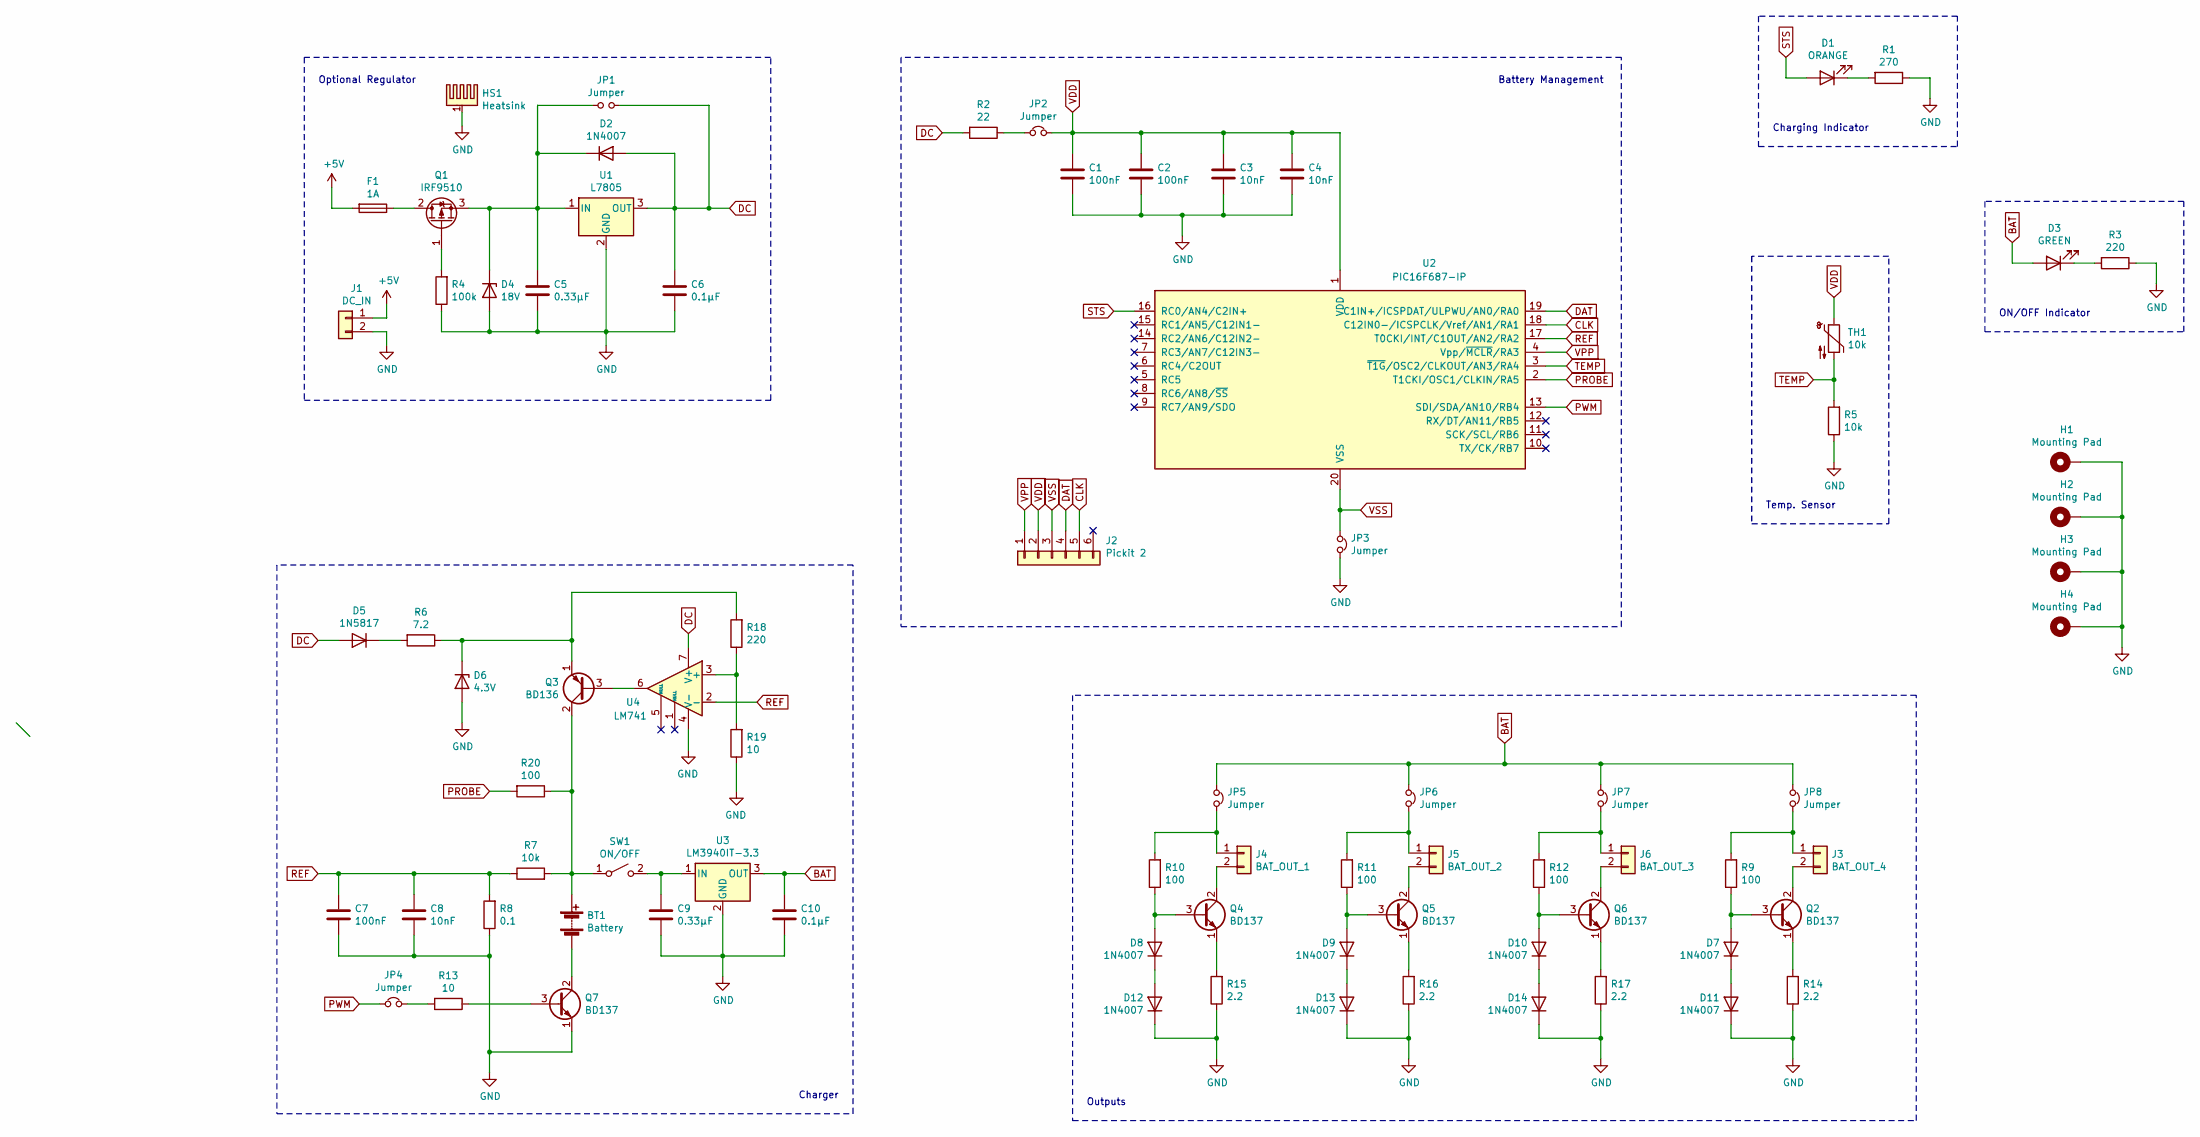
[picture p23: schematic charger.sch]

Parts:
BT1: Battery; TerminalBlock_4Ucon_1x02_P3.50mm_Horizontal
C1, C2, C7: 100nF; C_Disc_D3.0mm_W1.6mm_P2.50mm
C3, C4, C8: 10nF; C_Disc_D3.0mm_W1.6mm_P2.50mm
C5, C9: 0.33μF; C_Disc_D3.0mm_W1.6mm_P2.50mm
C6, C10: 0.1μF; C_Disc_D3.0mm_W1.6mm_P2.50mm
D1: ORANGE; Molex_KK-254_AE-6410-02A_1x02_P2.54mm_Vertical
D2, D7, D8, D9, D10, D11, D12, D13, D14: 1N4007; D_DO-41_SOD81_P10.16mm_Horizontal
D3: GREEN; Molex_KK-254_AE-6410-02A_1x02_P2.54mm_Vertical
D4: 18V; D_DO-41_SOD81_P10.16mm_Horizontal
D5: 1N5817; D_DO-41_SOD81_P10.16mm_Horizontal
D6: 4.3V; D_DO-41_SOD81_P10.16mm_Horizontal
F1: 1A; Fuseholder_Cylinder-5x20mm_Stelvio-Kontek_PTF78_Horizontal_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
H1, H2, H3, H4: Mounting Pad; MountingHole_3.2mm_M3_Pad_Via
HS1: Heatsink; Heatsink_Fischer_SK104-STCB_35x13mm__2xDrill3.5mm_ScrewM3
J1: DC_IN; TerminalBlock_4Ucon_1x02_P3.50mm_Horizontal
J2: Pickit 2; PinSocket_1x06_P2.54mm_Vertical
J3: BAT_OUT_4; TerminalBlock_4Ucon_1x02_P3.50mm_Horizontal
J4: BAT_OUT_1; TerminalBlock_4Ucon_1x02_P3.50mm_Horizontal
J5: BAT_OUT_2; TerminalBlock_4Ucon_1x02_P3.50mm_Horizontal
J6: BAT_OUT_3; TerminalBlock_4Ucon_1x02_P3.50mm_Horizontal
JP1, JP2, JP3, JP4, JP5, JP6, JP7, JP8: Jumper; PinHeader_1x02_P2.54mm_Vertical
Q1: IRF9510; TO-220-3_Vertical
Q2, Q4, Q5, Q6, Q7: BD137; TO-126-3_Vertical
Q3: BD136; TO-126-3_Vertical
R1: 270; R_Axial_DIN0207_L6.3mm_D2.5mm_P10.16mm_Horizontal
R2: 22; R_Axial_DIN0414_L11.9mm_D4.5mm_P5.08mm_Vertical
R3, R18: 220; R_Axial_DIN0207_L6.3mm_D2.5mm_P10.16mm_Horizontal
R4: 100k; R_Axial_DIN0207_L6.3mm_D2.5mm_P10.16mm_Horizontal
R5, R7: 10k; R_Axial_DIN0207_L6.3mm_D2.5mm_P10.16mm_Horizontal
R6: 7.2; R_Axial_DIN0516_L15.5mm_D5.0mm_P5.08mm_Vertical
R8: 0.1; R_Axial_DIN0207_L6.3mm_D2.5mm_P10.16mm_Horizontal
R9, R10, R11, R12, R20: 100; R_Axial_DIN0207_L6.3mm_D2.5mm_P10.16mm_Horizontal
R13, R19: 10; R_Axial_DIN0207_L6.3mm_D2.5mm_P10.16mm_Horizontal
R14, R15, R16, R17: 2.2; R_Axial_DIN0207_L6.3mm_D2.5mm_P10.16mm_Horizontal
SW1: ON/OFF; Molex_KK-254_AE-6410-02A_1x02_P2.54mm_Vertical
TH1: 10k; Molex_KK-254_AE-6410-02A_1x02_P2.54mm_Vertical
U1: L7805; TO-220-3_Vertical
U2: PIC16F687-IP; DIP-20_W7.62mm_Socket
U3: LM3940IT-3.3; TO-220-3_Vertical
U4: LM741; DIP-8_W7.62mm_Socket

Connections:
+5V: F1.2, J1.1
BAT: C10.1, D3.2 (A), JP5.1, JP6.1, JP7.1, JP8.1, U3.3 (OUT)
CLK: J2.5, U2.18 (C12IN0-/ICSPCLK/Vref/AN1/RA1)
DAT: J2.4, U2.19 (C1IN+/ICSPDAT/ULPWU/AN0/RA0)
DC: C6.1, D2.2 (A), D5.2 (A), JP1.2, R2.2, U1.3 (OUT), U4.7 (V+)
GND: C1.2, C2.2, C3.2, C4.2, C5.2, C6.2, C7.2, C8.2, C9.2, C10.2, D4.2 (A), D6.2 (A), D11.1 (K), D12.1 (K), D13.1 (K), D14.1 (K), H1.1, H2.1, H3.1, H4.1, HS1.1, J1.2, JP3.2, Q7.1 (E), R1.1, R3.1, R4.1, R5.1, R8.1, R14.1, R15.1, R16.1, R17.1, R19.1, U1.2 (GND), U3.2 (GND), U4.4 (V-)
unnamed: BT1.1 (+), Q3.2 (C), R7.2, R20.1, SW1.1 (A)
unnamed: BT1.2 (-), Q7.2 (C)
unnamed: C5.1, D2.1 (K), D4.1 (K), JP1.1, Q1.3 (S), U1.1 (IN)
unnamed: C9.1, SW1.2 (B), U3.1 (IN)
unnamed: D1.1 (K), R1.2
unnamed: D3.1 (K), R3.2
unnamed: D5.1 (K), R6.2
unnamed: D6.1 (K), Q3.1 (E), R6.1, R18.2
unnamed: D7.2 (A), Q2.3 (B), R9.1
unnamed: D8.2 (A), Q4.3 (B), R10.1
unnamed: D9.2 (A), Q5.3 (B), R11.1
unnamed: D10.1 (K), D14.2 (A)
unnamed: D10.2 (A), Q6.3 (B), R12.1
unnamed: D7.1 (K), D11.2 (A)
unnamed: D8.1 (K), D12.2 (A)
unnamed: D9.1 (K), D13.2 (A)
unnamed: F1.1, Q1.2 (D)
unnamed: J3.1, JP8.2, R9.2
unnamed: J3.2, Q2.2 (C)
unnamed: J4.1, JP5.2, R10.2
unnamed: J4.2, Q4.2 (C)
unnamed: J5.1, JP6.2, R11.2
unnamed: J5.2, Q5.2 (C)
unnamed: J6.1, JP7.2, R12.2
unnamed: J6.2, Q6.2 (C)
unnamed: JP2.1, R2.1
unnamed: JP4.2, R13.2
unnamed: Q1.1 (G), R4.2
unnamed: Q2.1 (E), R14.2
unnamed: Q3.3 (B), U4.6
unnamed: Q4.1 (E), R15.2
unnamed: Q5.1 (E), R16.2
unnamed: Q6.1 (E), R17.2
unnamed: Q7.3 (B), R13.1
unnamed: R18.1, R19.2, U4.3 (+)
PROBE: R20.2, U2.2 (T1CKI/OSC1/CLKIN/RA5)
PWM: JP4.1, U2.13 (SDI/SDA/AN10/RB4)
REF: C7.1, C8.1, R7.1, R8.2, U2.17 (T0CKI/INT/C1OUT/AN2/RA2), U4.2 (-)
STS: D1.2 (A), U2.16 (RC0/AN4/C2IN+)
TEMP: R5.2, TH1.2, U2.3 (~T1G~/OSC2/CLKOUT/AN3/RA4)
VDD: C1.1, C2.1, C3.1, C4.1, J2.2, JP2.2, TH1.1, U2.1 (VDD)
VPP: J2.1, U2.4 (Vpp/~MCLR~/RA3)
VSS: J2.3, JP3.1, U2.20 (VSS)

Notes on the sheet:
Charging Indicator
Temp. Sensor
Optional Regulator
Battery Management
ON/OFF Indicator
Outputs
Charger

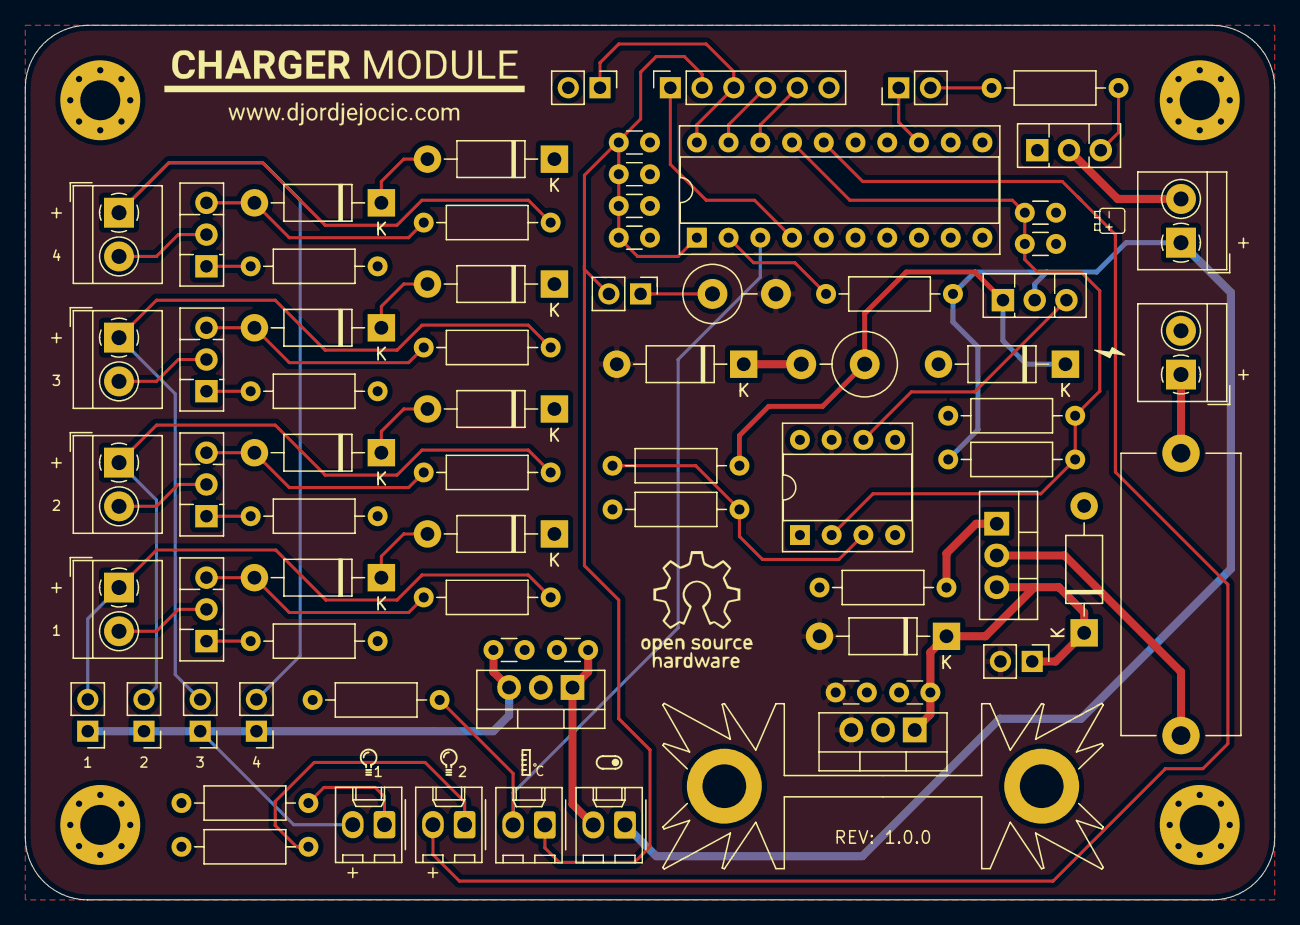
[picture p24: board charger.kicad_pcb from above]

Board: 2 copper layers, 100.0 x 70.0 mm, 78 parts (0 on the bottom side), 49 nets.

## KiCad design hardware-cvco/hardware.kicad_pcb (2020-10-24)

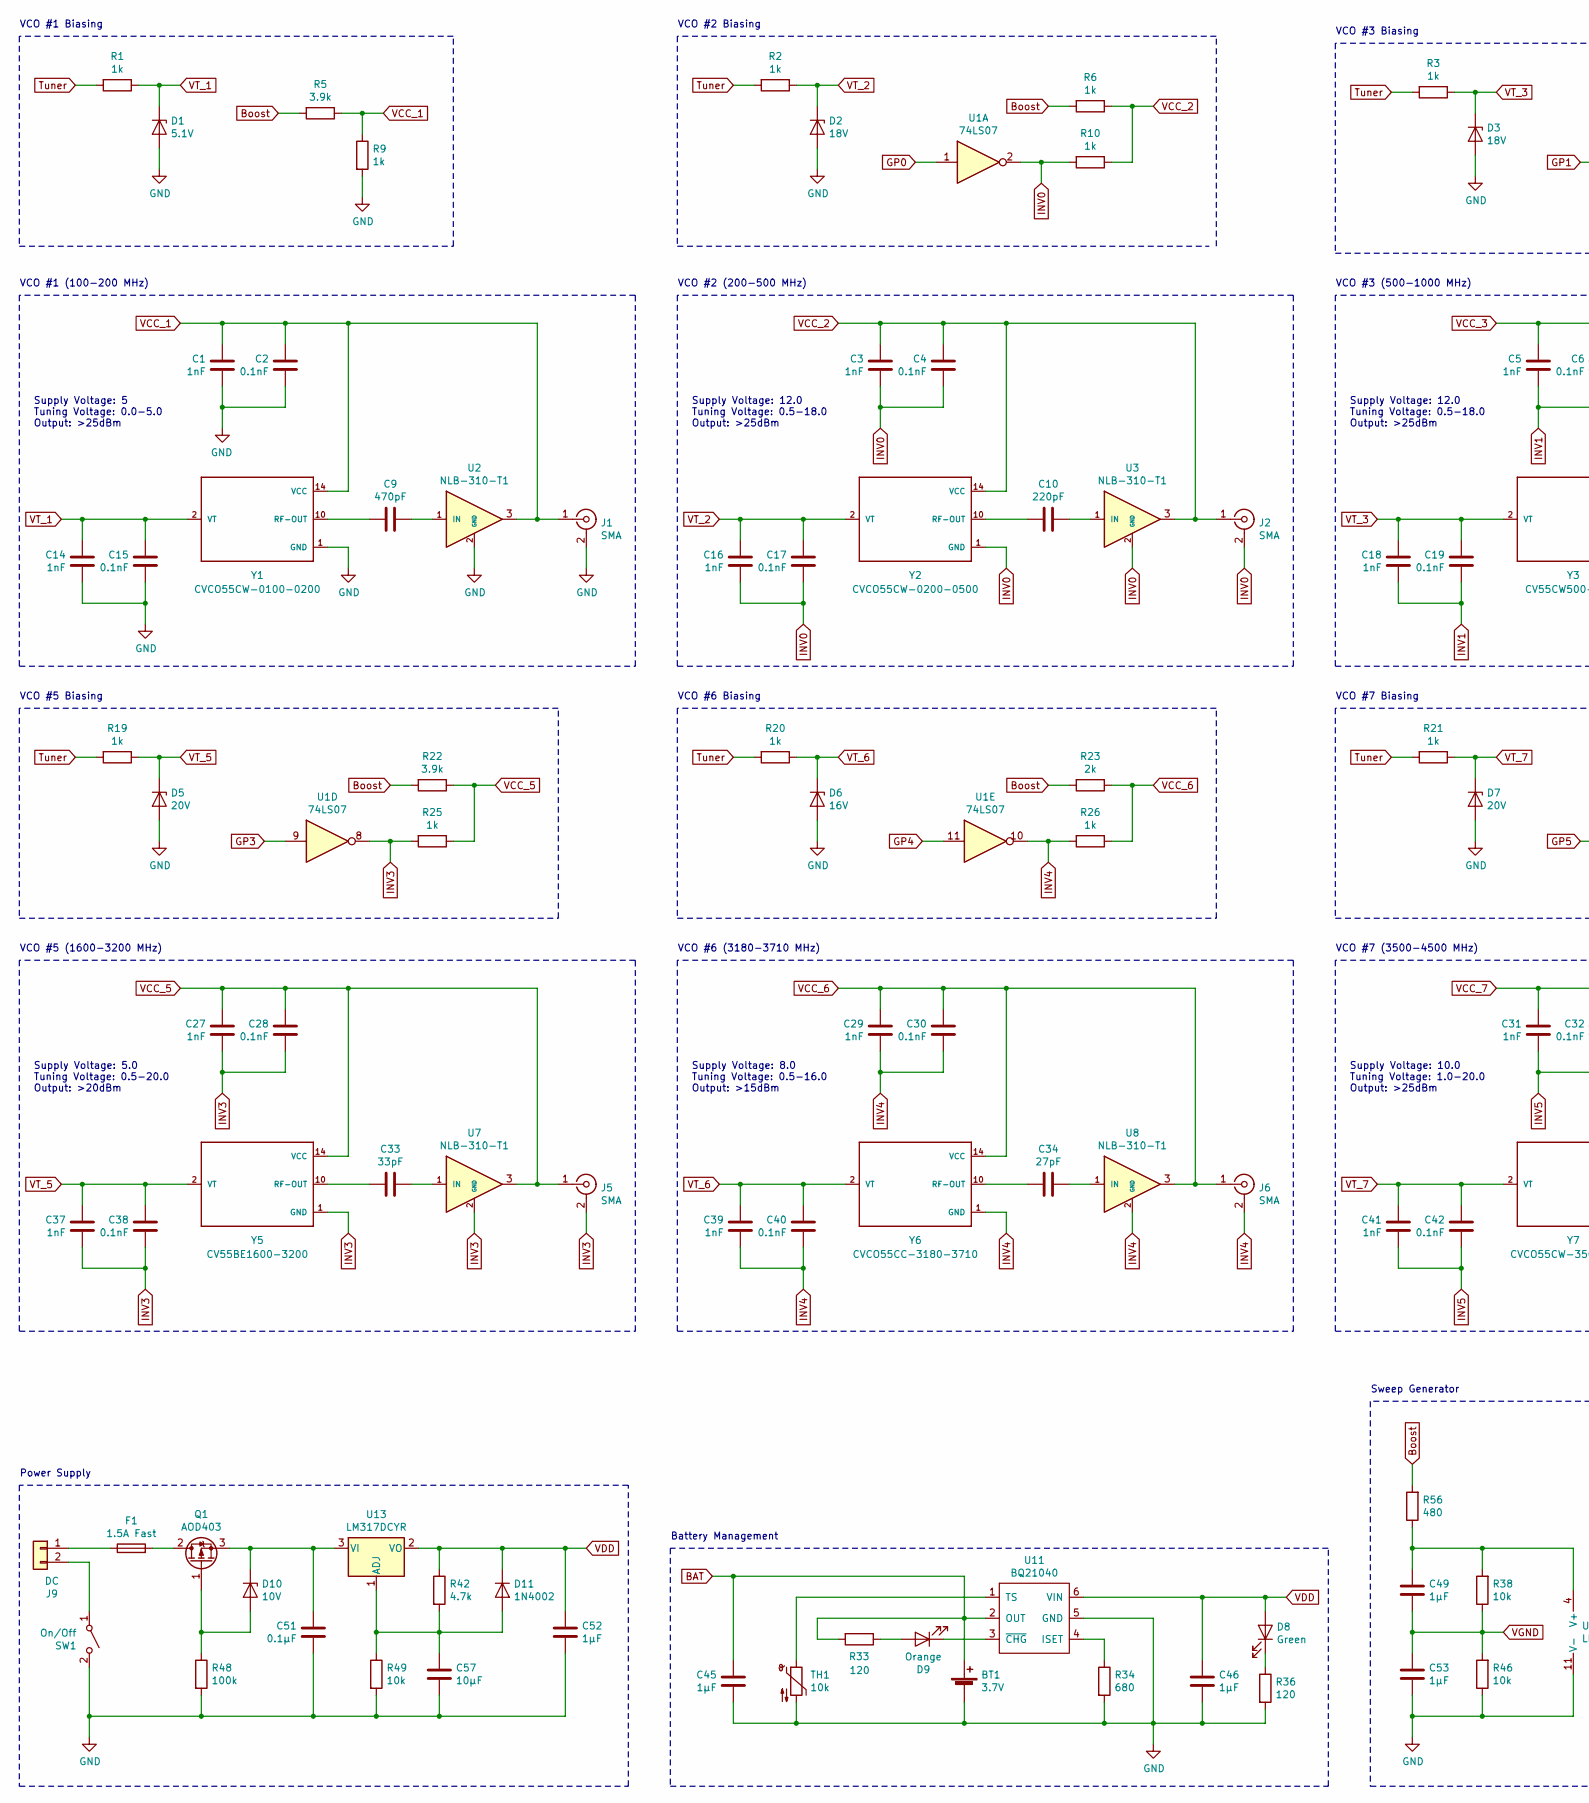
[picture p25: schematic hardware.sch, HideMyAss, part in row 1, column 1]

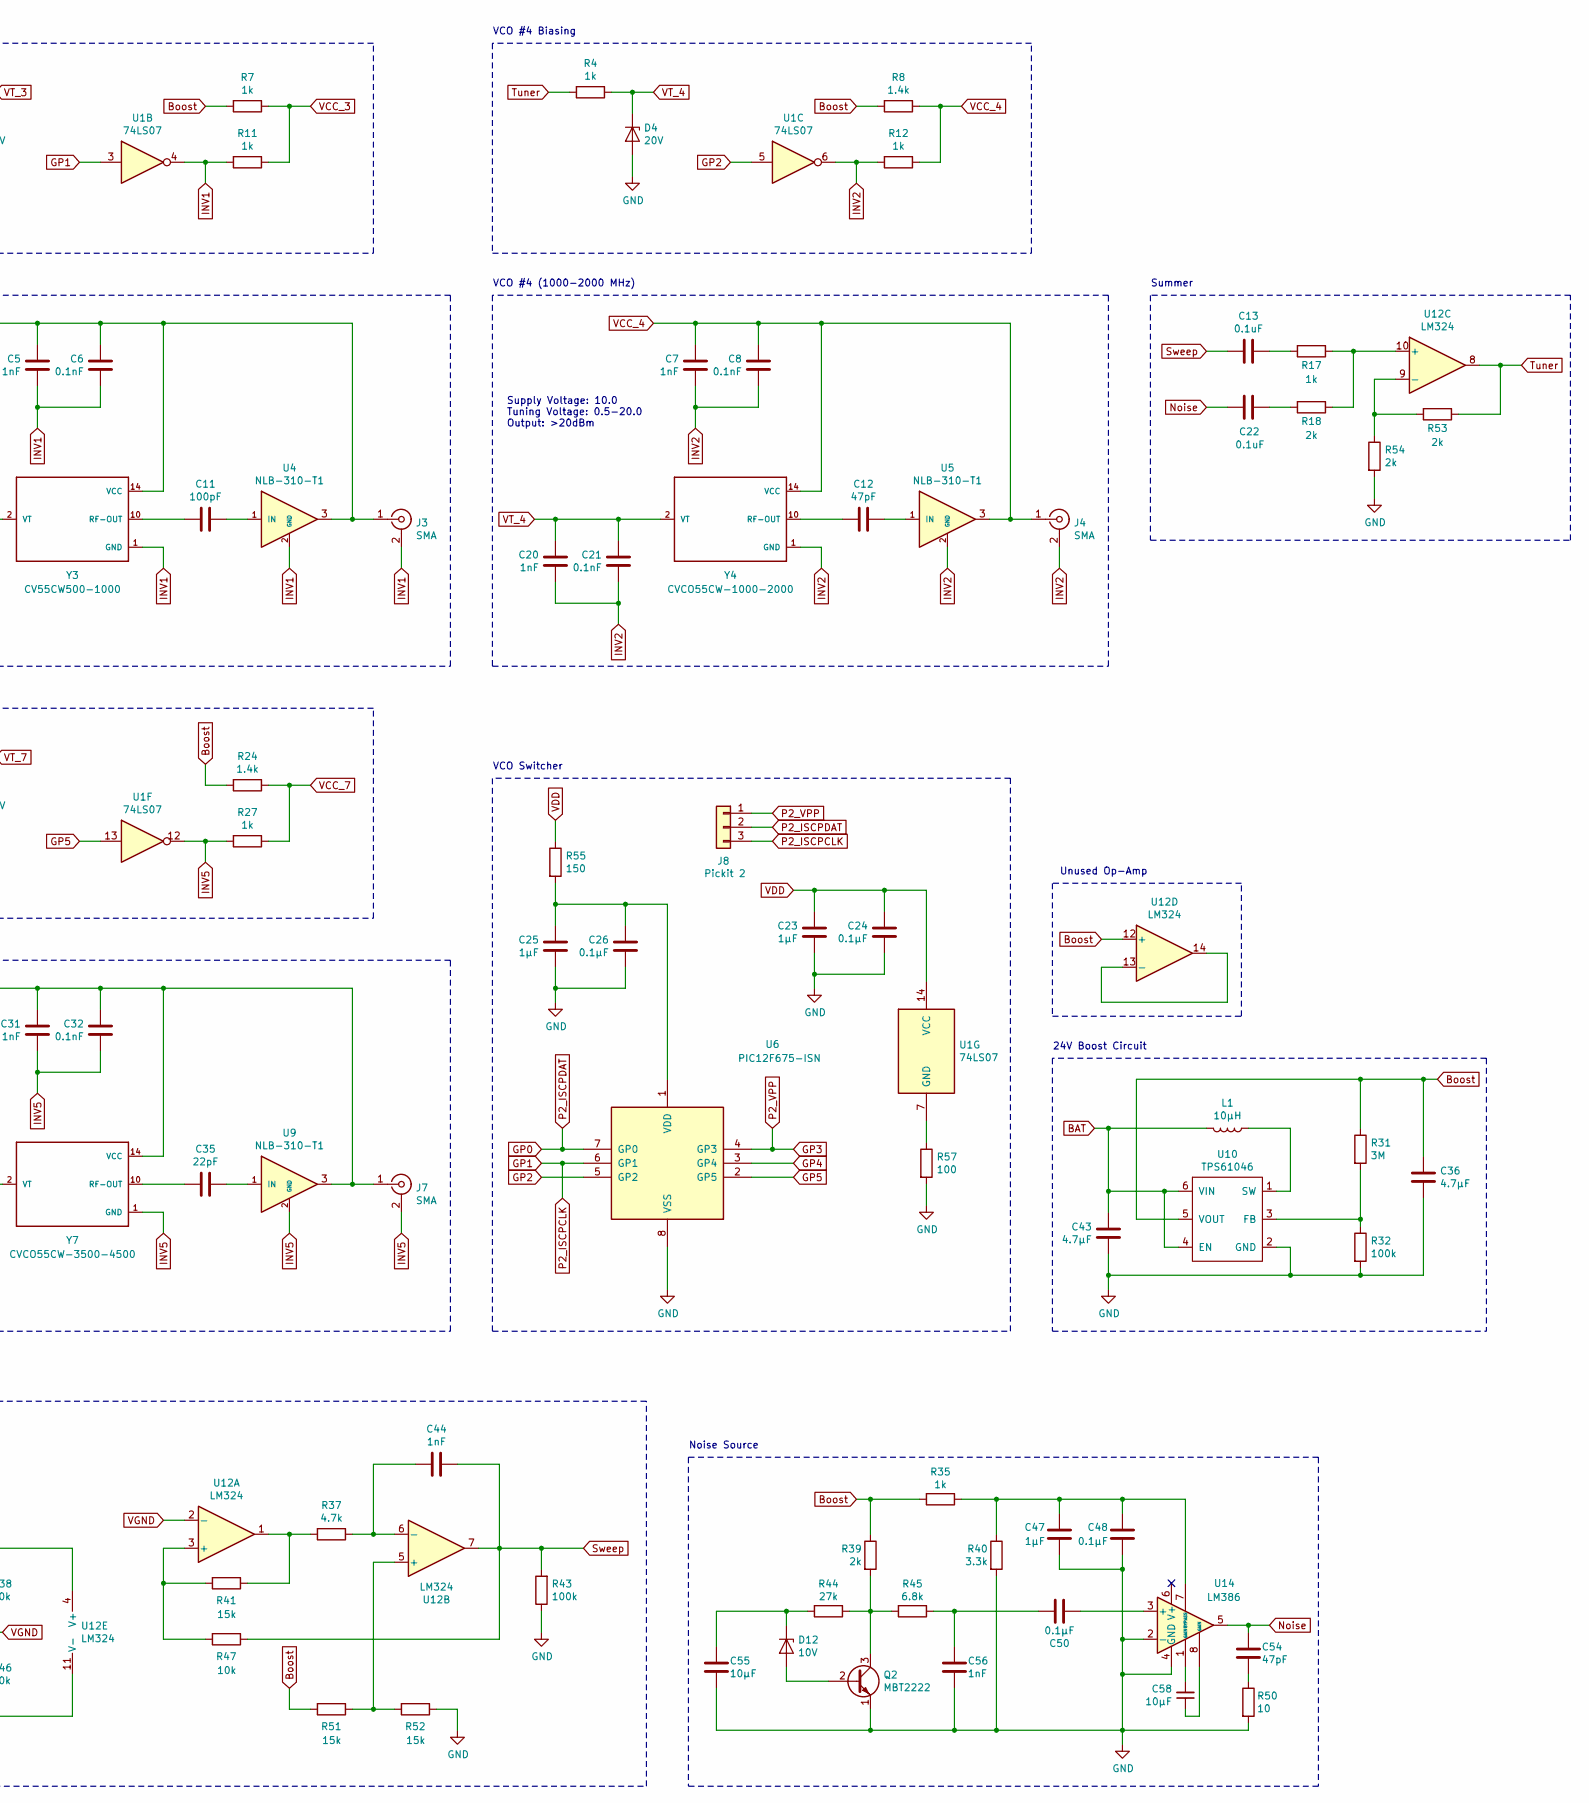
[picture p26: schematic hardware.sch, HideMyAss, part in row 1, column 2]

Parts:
BT1: 3.7V; 2-2.54mm-Horizontal-Molex; LCSC Part # C132504
C1, C3, C5, C7, C14, C16, C18, C20, C27, C29, C31, C37, C39, C41: 1nF; C_0805_2012Metric_Pad1.15x1.40mm_HandSolder; LCSC Part # C1791
C2, C4, C6, C8, C15, C17, C19, C21, C28, C30, C32, C38, C40, C42: 0.1nF; C_0805_2012Metric_Pad1.15x1.40mm_HandSolder; LCSC Part # C159771
C9: 470pF; C_0805_2012Metric_Pad1.15x1.40mm_HandSolder; LCSC Part # C1743
C10: 220pF; C_0805_2012Metric_Pad1.15x1.40mm_HandSolder; LCSC Part # C1727
C11: 100pF; C_0805_2012Metric_Pad1.15x1.40mm_HandSolder; LCSC Part # C1790
C12, C54: 47pF; C_0805_2012Metric_Pad1.15x1.40mm_HandSolder; LCSC Part # C107118
C13, C22: 0.1uF; C_0805_2012Metric_Pad1.15x1.40mm_HandSolder; LCSC Part # C62912
C23, C25, C45, C46, C47, C49, C53: 1μF; C_0805_2012Metric_Pad1.15x1.40mm_HandSolder; LCSC Part # C116352
C24, C26: 0.1μF; C_0805_2012Metric_Pad1.15x1.40mm_HandSolder; LCSC Part # C62912
C33: 33pF; C_0805_2012Metric_Pad1.15x1.40mm_HandSolder; LCSC Part # C157687
C34: 27pF; C_0805_2012Metric_Pad1.15x1.40mm_HandSolder; LCSC Part # C8031
C35: 22pF; C_0805_2012Metric_Pad1.15x1.40mm_HandSolder; LCSC Part # C24658
C36, C43: 4.7μF; C_0805_2012Metric_Pad1.15x1.40mm_HandSolder; LCSC Part # C37818
C44, C56: 1nF; C_0805_2012Metric_Pad1.15x1.40mm_HandSolder
C48, C50: 0.1μF; C_0805_2012Metric_Pad1.15x1.40mm_HandSolder
C51: 0.1μF; C_0805_2012Metric_Pad1.15x1.40mm_HandSolder; LCSC Part # C38141
C52: 1μF; C_0805_2012Metric_Pad1.15x1.40mm_HandSolder; LCSC Part # C215803
C55, C58: 10μF; C_0805_2012Metric_Pad1.15x1.40mm_HandSolder
C57: 10μF; C_0805_2012Metric_Pad1.15x1.40mm_HandSolder; LCSC Part # C40894
D1: 5.1V; D_MiniMELF; LCSC Part # C305343
D2, D3: 18V; D_MiniMELF; LCSC Part # C268731
D4, D5, D7: 20V; D_MiniMELF; LCSC Part # C398899
D6: 16V; D_MiniMELF; LCSC Part # C313481
D8: Green; 2-2.54mm-Horizontal-Molex; LCSC Part # C99763
D9: Orange; 2-2.54mm-Horizontal-Molex; LCSC Part # C99759
D10, D12: 10V; D_MiniMELF; LCSC Part # C398894
D11: 1N4002; D_SMA; LCSC Part # C433393
F1: 1.5A Fast; Fuse_1206_3216Metric_Pad1.42x1.75mm_HandSolder; LCSC Part # C151143
J1, J2, J3, J4, J5, J6, J7: SMA; SMA-Edge; LCSC Part # C530661
J8: Pickit 2; PinSocket_1x03_P2.54mm_Horizontal; LCSC Part # C49257
J9: DC; SolderWirePad_1x02_P3.81mm_Drill1mm
L1: 10μH; C_0805_2012Metric_Pad1.15x1.40mm_HandSolder; LCSC Part # C1046
Q1: AOD403; TO-252-2; LCSC Part # C28969
Q2: MBT2222; SOT-23; LCSC Part # C82460
R1, R6, R7, R9, R10, R11, R12, R17, R25, R26, R27: 1k; R_0805_2012Metric_Pad1.15x1.40mm_HandSolder; LCSC Part # C17513
R2, R3, R4, R19, R20, R21, R35: 1k; R_0805_2012Metric_Pad1.15x1.40mm_HandSolder
R5, R22: 3.9k; R_0805_2012Metric_Pad1.15x1.40mm_HandSolder; LCSC Part # C17614
R8, R24: 1.4k; R_0805_2012Metric_Pad1.15x1.40mm_HandSolder; LCSC Part # C17388
R18, R23, R53, R54: 2k; R_0805_2012Metric_Pad1.15x1.40mm_HandSolder; LCSC Part # C17604
R31: 3M; R_0805_2012Metric_Pad1.15x1.40mm_HandSolder; LCSC Part # C17662
R32, R43: 100k; R_0805_2012Metric_Pad1.15x1.40mm_HandSolder; LCSC Part # C149504
R33, R36: 120; R_0805_2012Metric_Pad1.15x1.40mm_HandSolder; LCSC Part # C111022
R34: 680; R_0805_2012Metric_Pad1.15x1.40mm_HandSolder; LCSC Part # C17798
R37, R42: 4.7k; R_0805_2012Metric_Pad1.15x1.40mm_HandSolder; LCSC Part # C47010
R38, R46, R47, R49: 10k; R_0805_2012Metric_Pad1.15x1.40mm_HandSolder; LCSC Part # C55866
R39: 2k; R_0805_2012Metric_Pad1.15x1.40mm_HandSolder
R40: 3.3k; R_0805_2012Metric_Pad1.15x1.40mm_HandSolder; LCSC Part # C26010
R41, R51, R52: 15k; R_0805_2012Metric_Pad1.15x1.40mm_HandSolder; LCSC Part # C17475
R44: 27k; R_0805_2012Metric_Pad1.15x1.40mm_HandSolder; LCSC Part # C17593
R45: 6.8k; R_0805_2012Metric_Pad1.15x1.40mm_HandSolder; LCSC Part # C17772
R48: 100k; R_0805_2012Metric_Pad1.15x1.40mm_HandSolder; LCSC Part # C55868
R50: 10; R_0805_2012Metric_Pad1.15x1.40mm_HandSolder
R55: 150; R_0805_2012Metric_Pad1.15x1.40mm_HandSolder; LCSC Part # C17513
R56: 480; R_0805_2012Metric_Pad1.15x1.40mm_HandSolder; LCSC Part # C55866
R57: 100; R_0805_2012Metric_Pad1.15x1.40mm_HandSolder; LCSC Part # C17513
SW1: On/Off; 2-2.54mm-Horizontal-Molex; LCSC Part # C505003
TH1: 10k; 2-2.54mm-Horizontal-Molex; LCSC Part # C13879
U1: 74LS07; SOIC-14_3.9x8.7mm_P1.27mm; LCSC Part # C513513
U2, U3, U4, U5, U7, U8, U9: NLB-310-T1; Micro-X-4; Mouser Part # 772-NLB-310
U6: PIC12F675-ISN; SOIC-8_3.9x4.9mm_P1.27mm; LCSC Part # C96100
U10: TPS61046; SOT-23-6_Handsoldering; LCSC Part # C464815
U11: BQ21040; SOT-23-6; LCSC Part # C202311
U12: LM324; SOIC-14_3.9x8.7mm_P1.27mm
U13: LM317DCYR; SOT-223-3_TabPin2; LCSC Part # C51466
U14: LM386; SO-8_5.3x6.2mm_P1.27mm
Y1: CVCO55CW-0100-0200; CVCO55; Mouser Part # 549-CV55CW0100-0200
Y2: CVCO55CW-0200-0500; CVCO55; Mouser Part # 549-CV55CW0200-0500
Y3: CV55CW500-1000; CVCO55; Mouser Part # 549-CV55CW500-1000
Y4: CVCO55CW-1000-2000; CVCO55; Mouser Part # 549-CV55CW1000-2000
Y5: CV55BE1600-3200; CVCO55; Mouser Part # 549-CV55BE1600-3200
Y6: CVCO55CC-3180-3710; CVCO55; Mouser Part # 549-CVCO55CC31803710
Y7: CVCO55CW-3500-4500; CVCO55; Mouser Part # 549-CVC55CW3500-4500

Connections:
BAT: BT1.1 (+), C43.1, C45.1, L1.2, R33.2, U10.4 (EN), U10.6 (VIN), U11.2 (OUT)
Boost: C36.1, R5.2, R6.2, R7.2, R8.2, R22.2, R23.2, R24.2, R31.1, R35.2, R39.1, R51.2, R56.2, U10.5 (VOUT), U12.12 (+)
GND: BT1.2 (-), C1.2, C2.2, C14.2, C15.2, C23.2, C24.2, C25.2, C26.2, C36.2, C43.2, C45.2, C46.2, C47.1, C48.1, C51.2, C52.2, C53.2, C55.1, C56.1, C57.2, D1.2 (A), D2.2 (A), D3.2 (A), D4.2 (A), D5.2 (A), D6.2 (A), D7.2 (A), J1.2 (Ext), Q2.1 (E), R9.2, R32.2, R34.2, R36.2, R40.2, R43.1, R46.1, R48.2, R49.2, R50.2, R52.1, R54.2, R57.2, SW1.2 (B), TH1.2, U2.2 (GND), U2.4 (GND), U6.8 (VSS), U10.2 (GND), U11.5 (GND), U12.11 (V-), U14.2 (-), U14.4 (GND), Y1.1 (GND), Y1.3 (GND), Y1.4 (GND), Y1.5 (GND), Y1.6 (GND), Y1.7 (GND), Y1.8 (GND), Y1.9 (GND), Y1.11 (GND), Y1.12 (GND), Y1.13 (GND), Y1.15 (GND), Y1.16 (GND)
GP0: J8.2, U1.1, U6.7 (GP0)
GP1: J8.3, U1.3, U6.6 (GP1)
GP2: U1.5, U6.5 (GP2)
GP3: J8.1, U1.9, U6.4 (GP3)
GP4: U1.11, U6.3 (GP4)
GP5: U1.13, U6.2 (GP5)
INV0: C3.2, C4.2, C16.2, C17.2, J2.2 (Ext), R10.2, U1.2, U3.2 (GND), U3.4 (GND), Y2.1 (GND), Y2.3 (GND), Y2.4 (GND), Y2.5 (GND), Y2.6 (GND), Y2.7 (GND), Y2.8 (GND), Y2.9 (GND), Y2.11 (GND), Y2.12 (GND), Y2.13 (GND), Y2.15 (GND), Y2.16 (GND)
INV1: C5.2, C6.2, C18.2, C19.2, J3.2 (Ext), R11.2, U1.4, U4.2 (GND), U4.4 (GND), Y3.1 (GND), Y3.3 (GND), Y3.4 (GND), Y3.5 (GND), Y3.6 (GND), Y3.7 (GND), Y3.8 (GND), Y3.9 (GND), Y3.11 (GND), Y3.12 (GND), Y3.13 (GND), Y3.15 (GND), Y3.16 (GND)
INV2: C7.2, C8.2, C20.2, C21.2, J4.2 (Ext), R12.2, U1.6, U5.2 (GND), U5.4 (GND), Y4.1 (GND), Y4.3 (GND), Y4.4 (GND), Y4.5 (GND), Y4.6 (GND), Y4.7 (GND), Y4.8 (GND), Y4.9 (GND), Y4.11 (GND), Y4.12 (GND), Y4.13 (GND), Y4.15 (GND), Y4.16 (GND)
INV3: C27.2, C28.2, C37.2, C38.2, J5.2 (Ext), R25.2, U1.8, U7.2 (GND), U7.4 (GND), Y5.1 (GND), Y5.3 (GND), Y5.4 (GND), Y5.5 (GND), Y5.6 (GND), Y5.7 (GND), Y5.8 (GND), Y5.9 (GND), Y5.11 (GND), Y5.12 (GND), Y5.13 (GND), Y5.15 (GND), Y5.16 (GND)
INV4: C29.2, C30.2, C39.2, C40.2, J6.2 (Ext), R26.2, U1.10, U8.2 (GND), U8.4 (GND), Y6.1 (GND), Y6.3 (GND), Y6.4 (GND), Y6.5 (GND), Y6.6 (GND), Y6.7 (GND), Y6.8 (GND), Y6.9 (GND), Y6.11 (GND), Y6.12 (GND), Y6.13 (GND), Y6.15 (GND), Y6.16 (GND)
INV5: C31.2, C32.2, C41.2, C42.2, J7.2 (Ext), R27.2, U1.12, U9.2 (GND), U9.4 (GND), Y7.1 (GND), Y7.3 (GND), Y7.4 (GND), Y7.5 (GND), Y7.6 (GND), Y7.7 (GND), Y7.8 (GND), Y7.9 (GND), Y7.11 (GND), Y7.12 (GND), Y7.13 (GND), Y7.15 (GND), Y7.16 (GND)
unnamed: C9.1, U2.1 (IN)
unnamed: C9.2, Y1.10 (RF-OUT)
unnamed: C10.1, U3.1 (IN)
unnamed: C10.2, Y2.10 (RF-OUT)
unnamed: C11.1, U4.1 (IN)
unnamed: C11.2, Y3.10 (RF-OUT)
unnamed: C12.1, U5.1 (IN)
unnamed: C12.2, Y4.10 (RF-OUT)
unnamed: C13.1, R17.2
unnamed: C22.1, R18.2
unnamed: C25.1, C26.1, R55.2, U6.1 (VDD)
unnamed: C33.1, U7.1 (IN)
unnamed: C33.2, Y5.10 (RF-OUT)
unnamed: C34.1, U8.1 (IN)
unnamed: C34.2, Y6.10 (RF-OUT)
unnamed: C35.1, U9.1 (IN)
unnamed: C35.2, Y7.10 (RF-OUT)
unnamed: C44.2, R37.1, U12.6 (-)
unnamed: C47.2, C48.2, R35.1, R40.1, U14.7 (BYPASS)
unnamed: C49.1, R38.2, R56.1, U12.4 (V+)
unnamed: C50.1, C56.2, R45.1
unnamed: C50.2, U14.3 (+)
unnamed: C51.1, D10.1 (K), Q1.3 (S), U13.3 (VI)
unnamed: C54.2, R50.1
unnamed: C55.2, D12.1 (K), R44.2
unnamed: C57.1, D11.2 (A), R42.2, R49.1, U13.1 (ADJ)
unnamed: C58.1, U14.8 (GAIN)
unnamed: C58.2, U14.1 (GAIN)
unnamed: D8.1 (K), R36.1
unnamed: D9.1 (K), U11.3 (~CHG~)
unnamed: D9.2 (A), R33.1
unnamed: D10.2 (A), Q1.1 (G), R48.1
unnamed: D12.2 (A), Q2.2 (B)
unnamed: F1.1, J9.1
unnamed: F1.2, Q1.2 (D)
unnamed: J9.2, SW1.1 (A)
unnamed: L1.1, U10.1 (SW)
unnamed: Q2.3 (C), R39.2, R44.1, R45.2
unnamed: R17.1, R18.1, U12.10 (+)
unnamed: R31.2, R32.1, U10.3 (FB)
unnamed: R34.1, U11.4 (ISET)
unnamed: R37.2, R41.1, U12.1
unnamed: R41.2, R47.2, U12.3 (+)
unnamed: R51.1, R52.2, U12.5 (+)
unnamed: R53.2, R54.1, U12.9 (-)
unnamed: R57.1, U1.7 (GND)
unnamed: TH1.1, U11.1 (TS)
unnamed: U12.13 (-), U12.14
Noise: C22.2, C54.1, U14.5
Sweep: C13.2, C44.1, R43.2, R47.1, U12.7
Tuner: R1.2, R2.2, R3.2, R4.2, R19.2, R20.2, R21.2, R53.1, U12.8
VCC_1: C1.1, C2.1, J1.1 (In), R5.1, R9.1, U2.3, Y1.14 (VCC)
VCC_2: C3.1, C4.1, J2.1 (In), R6.1, R10.1, U3.3, Y2.14 (VCC)
VCC_3: C5.1, C6.1, J3.1 (In), R7.1, R11.1, U4.3, Y3.14 (VCC)
VCC_4: C7.1, C8.1, J4.1 (In), R8.1, R12.1, U5.3, Y4.14 (VCC)
VCC_5: C27.1, C28.1, J5.1 (In), R22.1, R25.1, U7.3, Y5.14 (VCC)
VCC_6: C29.1, C30.1, J6.1 (In), R23.1, R26.1, U8.3, Y6.14 (VCC)
VCC_7: C31.1, C32.1, J7.1 (In), R24.1, R27.1, U9.3, Y7.14 (VCC)
VDD: C23.1, C24.1, C46.1, C52.1, D8.2 (A), D11.1 (K), R42.1, R55.1, U1.14 (VCC), U11.6 (VIN), U13.2 (VO)
VGND: C49.2, C53.1, R38.1, R46.2, U12.2 (-)
VT_1: C14.1, C15.1, D1.1 (K), R1.1, Y1.2 (VT)
VT_2: C16.1, C17.1, D2.1 (K), R2.1, Y2.2 (VT)
VT_3: C18.1, C19.1, D3.1 (K), R3.1, Y3.2 (VT)
VT_4: C20.1, C21.1, D4.1 (K), R4.1, Y4.2 (VT)
VT_5: C37.1, C38.1, D5.1 (K), R19.1, Y5.2 (VT)
VT_6: C39.1, C40.1, D6.1 (K), R20.1, Y6.2 (VT)
VT_7: C41.1, C42.1, D7.1 (K), R21.1, Y7.2 (VT)

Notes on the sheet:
Supply Voltage: 12.0 Tuning Voltage: 0.5-18.0 Output: >25dBm
VCO #3 (500-1000 MHz)
Supply Voltage: 10.0 Tuning Voltage: 0.5-20.0 Output: >20dBm
VCO #4 (1000-2000 MHz)
Supply Voltage: 5.0 Tuning Voltage: 0.5-20.0 Output: >20dBm
VCO #5 (1600-3200 MHz)
Supply Voltage: 8.0 Tuning Voltage: 0.5-16.0 Output: >15dBm
VCO #6 (3180-3710 MHz)
Supply Voltage: 5 Tuning Voltage: 0.0-5.0 Output: >25dBm
VCO #1 (100-200 MHz)
VCO #1 Biasing
VCO #2 (200-500 MHz)
Supply Voltage: 10.0 Tuning Voltage: 1.0-20.0 Output: >25dBm
VCO #7 (3500-4500 MHz)
Power Supply
Battery Management
24V Boost Circuit
Sweep Generator
Summer
VCO Switcher
VCO #2 Biasing
VCO #3 Biasing
VCO #4 Biasing
VCO #5 Biasing
VCO #6 Biasing
VCO #7 Biasing
Noise Source
Unused Op-Amp

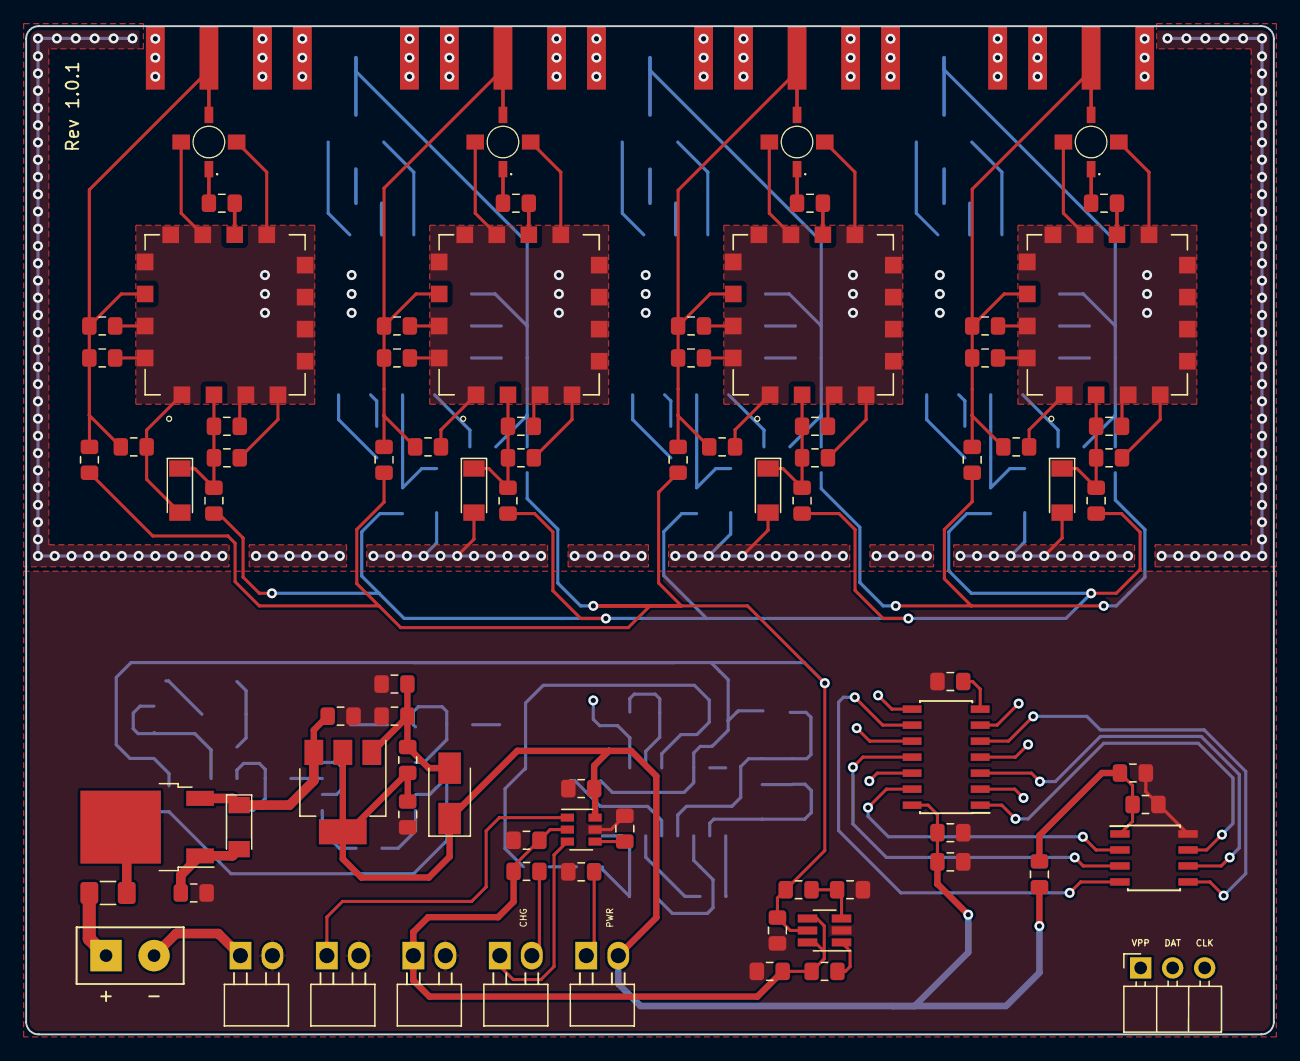
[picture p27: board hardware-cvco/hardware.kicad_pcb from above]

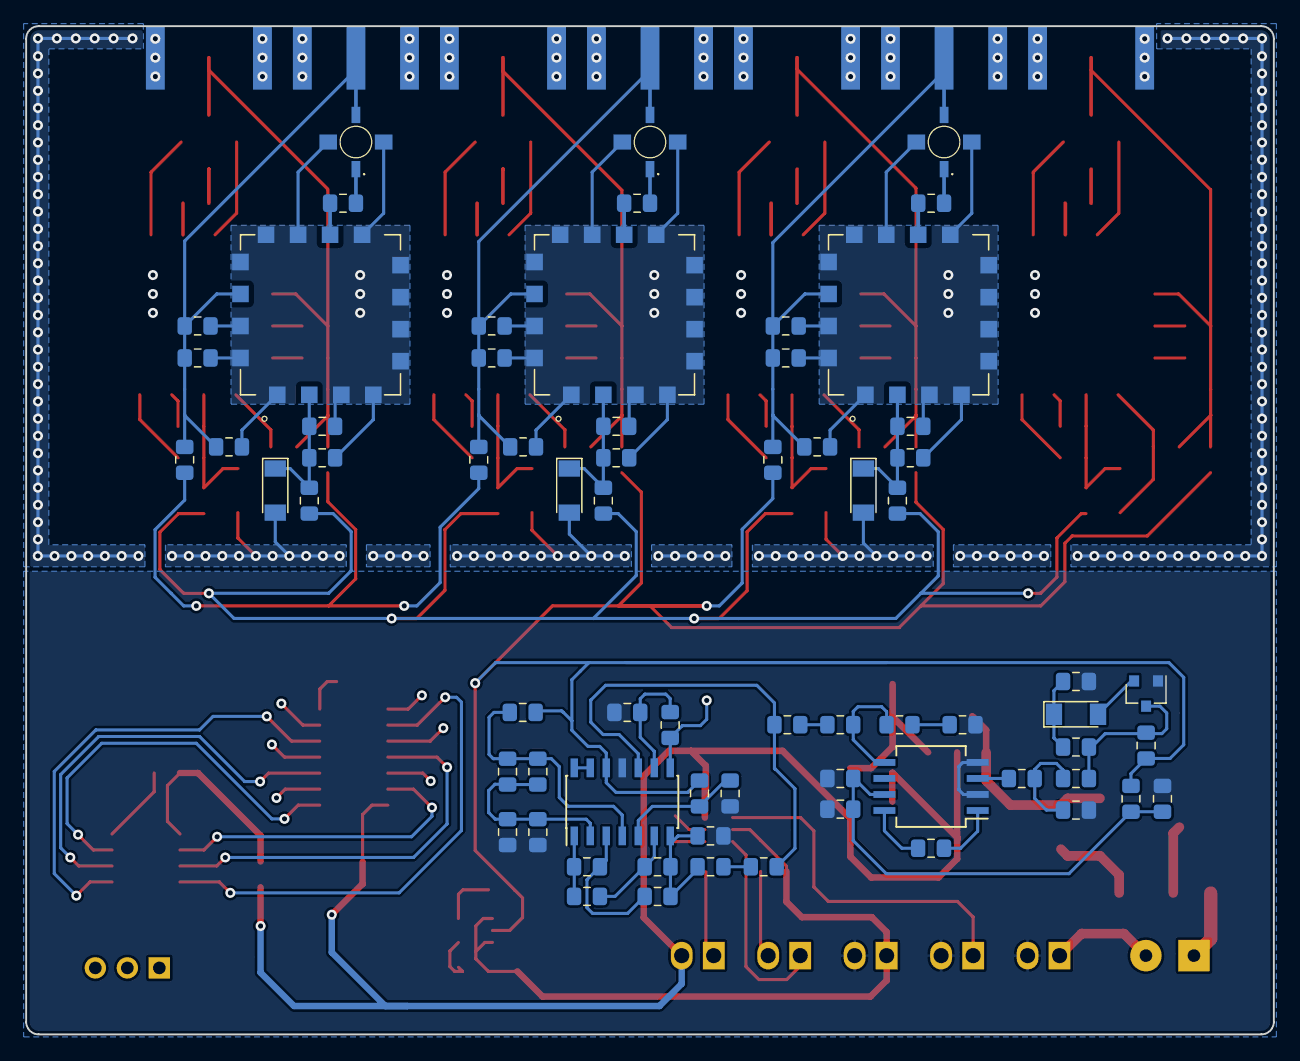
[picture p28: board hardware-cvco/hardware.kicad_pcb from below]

Board: 4 copper layers, 99.0 x 80.0 mm, 157 parts (71 on the bottom side), 82 nets.

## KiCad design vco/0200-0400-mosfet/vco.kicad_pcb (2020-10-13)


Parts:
C1: 470pF; C_Disc_D5.0mm_W2.5mm_P5.00mm
D1: 1N4148; D_DO-35_SOD27_P7.62mm_Horizontal
D2, D3: BB121; D_DO-35_SOD27_P2.54mm_Vertical_AnodeUp
J1: Terminal; TerminalBlock_4Ucon_1x03_P3.50mm_Horizontal
J2: Antenna; SMA_Amphenol_901-144_Vertical
L1: 100nH; L_Axial_L6.6mm_D2.7mm_P10.16mm_Horizontal_Vishay_IM-2
Q1, Q2: BS250; TO-92L_Wide
Q3, Q4: 2N7000; TO-92L_Wide
R1: 150; R_Axial_Power_L25.0mm_W9.0mm_P27.94mm
R2: 1k; R_Axial_DIN0516_L15.5mm_D5.0mm_P20.32mm_Horizontal

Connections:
unnamed: C1.1, D2.2 (A), L1.2, Q1.1 (D), Q2.2 (G), Q3.3 (D), Q4.2 (G)
unnamed: D1.1 (K), R1.1
unnamed: D2.1 (K), D3.1 (K), R2.2
unnamed: D3.2 (A), L1.1, Q1.2 (G), Q2.1 (D), Q3.2 (G), Q4.3 (D)
unnamed: Q1.3 (S), Q2.3 (S), R1.2
OUT: C1.2, J2.1 (In)
TUNE: J1.2, R2.1
VDD: D1.2 (A), J1.3
VSS: J1.1, J2.2 (Ext), Q3.1 (S), Q4.1 (S)

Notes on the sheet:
VDD: 24
Tune: 0-30
Output: 10dB


Board: 2 copper layers, 13 parts (0 on the bottom side), 9 nets.

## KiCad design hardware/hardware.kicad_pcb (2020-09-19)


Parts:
C1, C3, C5, C7, C9, C11: 100pf; C_0603_1608Metric_Pad1.05x0.95mm_HandSolder
C2, C4, C6, C8, C10, C12, C23, C24, C27: 10nF; C_0603_1608Metric_Pad1.05x0.95mm_HandSolder
C13, C14, C16, C19: 100p; C_0603_1608Metric_Pad1.05x0.95mm_HandSolder
C15: 100nF; C_0603_1608Metric_Pad1.05x0.95mm_HandSolder
C17: 820pF; C_0603_1608Metric_Pad1.05x0.95mm_HandSolder
C18: 12nF; C_0603_1608Metric_Pad1.05x0.95mm_HandSolder
C20, C21, C22: 1μF; C_0603_1608Metric_Pad1.05x0.95mm_HandSolder
C25, C26: 0.1μF; C_0603_1608Metric_Pad1.05x0.95mm_HandSolder
J1: RF A-N; SMA_Amphenol_901-144_Vertical
J2: RF A-P; SMA_Amphenol_901-144_Vertical
J3: RF B-N; SMA_Amphenol_901-144_Vertical
J4: RF B-P; SMA_Amphenol_901-144_Vertical
J5: Breakout; PinHeader_1x08_P2.54mm_Vertical
JP1: SW; PinHeader_1x02_P1.27mm_Vertical
R1, R4, R11, R14: 18; R_0603_1608Metric_Pad1.05x0.95mm_HandSolder
R2, R3, R5, R6, R12, R13, R15, R16: 300; R_0603_1608Metric_Pad1.05x0.95mm_HandSolder
R7: 4.7k; R_0603_1608Metric_Pad1.05x0.95mm_HandSolder
R8: 240; R_0603_1608Metric_Pad1.05x0.95mm_HandSolder
R9: 30; R_0603_1608Metric_Pad1.05x0.95mm_HandSolder
R10: 90; R_0603_1608Metric_Pad1.05x0.95mm_HandSolder
R17, R19, R21: 0; R_0603_1608Metric_Pad1.05x0.95mm_HandSolder
R18, R20, R22: 120; R_0603_1608Metric_Pad1.05x0.95mm_HandSolder
R23: 1m; R_0603_1608Metric_Pad1.05x0.95mm_HandSolder
U1: MAX2871ETJ+

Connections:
CE: R17.1, U1.4 (CE)
CLK: C23.1, R18.1, U1.1 (CLK)
CP_OUT: C15.2, C18.1, R8.1, U1.7 (CP_OUT)
DATA: C24.1, R20.1, U1.2 (DATA)
GND: C1.1, C2.1, C3.1, C4.1, C5.1, C6.1, C7.2, C8.2, C9.2, C10.2, C11.2, C12.2, C17.2, C18.2, C20.2, C21.2, C22.2, C23.2, C24.2, C26.2, C27.2, J1.2 (Ext), J2.2 (Ext), J3.2 (Ext), J4.2 (Ext), J5.2, R2.2, R3.2, R5.2, R6.2, R7.2, R10.1, R12.2, R13.2, R15.2, R16.2, R23.2, U1.8 (GND_CP), U1.9 (GND_PLL), U1.11 (GND_RF), U1.18 (GND_VCO), U1.21 (GND_TUNE), U1.27 (GND_DIG), U1.31 (GND_SD), U1.33 (EP); also elsewhere on the board
LD: U1.25 (LD)
LE: C27.1, R22.1, U1.3 (LE)
MUX: R19.1, U1.30 (MUX)
unnamed: C13.2, R1.2, R2.1
unnamed: C14.2, R4.2, R5.1
unnamed: C15.1, R9.2
unnamed: C16.2, R11.2, R12.1
unnamed: C19.2, R14.2, R15.1
unnamed: C20.1, U1.19 (NOISE_FILT)
unnamed: C21.1, U1.24 (REG)
unnamed: C22.1, U1.23 (BIAS_FILT)
unnamed 16: C25.1; also elsewhere on the board
unnamed: J1.1 (In), R1.1, R3.1
unnamed: J2.1 (In), R4.1, R6.1
unnamed: J3.1 (In), R11.1, R13.1
unnamed: J4.1 (In), R14.1, R16.1
unnamed: J5.3, R21.2
unnamed: J5.4, R19.2
unnamed: J5.5, R17.2
unnamed: J5.6, R18.2
unnamed: J5.7, R20.2
unnamed: J5.8, R22.2
unnamed: JP1.1, R9.1, R10.2
unnamed: R7.1, U1.22 (RSET)
RF_A_N: C13.1, U1.13 (RFOUTA_N)
RF_A_P: C14.1, U1.12 (RFOUTA_P)
RF_B_N: C16.1, U1.15 (RFOUTB_N)
RF_B_P: C19.1, U1.14 (RFOUTB_P)
RF_EN: R21.1, U1.26 (RFOUT_EN)
RF_REF: C25.2, R23.1, U1.29 (REF_IN)
SW: JP1.2, U1.5 (SW)
TUNE: C17.1, R8.2, U1.20 (TUNE)
VCC_CP: C1.2, C2.2, C3.2, C4.2, C5.2, C6.2, C7.1, C8.1, C9.1, C10.1, C11.1, C12.1, C26.1, J5.1, U1.6 (VCC_CP), U1.10 (VCC_PLL), U1.16 (VCC_RF), U1.17 (VCC_VCO), U1.28 (VCC_DIG), U1.32 (VCC_SD); also elsewhere on the board

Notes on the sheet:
50 MHz Reference
Decoupling
RF Output
Breakout
Loop Filter
VCO


Board: 4 copper layers, 58 parts (0 on the bottom side), 37 nets.

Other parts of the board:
X1: CXO_DIP14; Oscillator_DIP-14

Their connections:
GND: X1.7; also elsewhere on the board
unnamed 16: X1.8; also elsewhere on the board
VCC_CP: X1.1, X1.14; also elsewhere on the board

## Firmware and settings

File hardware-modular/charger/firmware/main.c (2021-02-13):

/*******************************************************************\
|* Author: Djordje Jocic                                           *|
|* Year: 2021                                                      *|
|* License: MIT License (MIT)                                      *|
|* =============================================================== *|
|* Personal Website: http://www.djordjejocic.com/                  *|
|* =============================================================== *|
|* Permission is hereby granted, free of charge, to any person     *|
|* obtaining a copy of this software and associated documentation  *|
|* files (the "Software"), to deal in the Software without         *|
|* restriction, including without limitation the rights to use,    *|
|* copy, modify, merge, publish, distribute, sublicense, and/or    *|
|* sell copies of the Software, and to permit persons to whom the  *|
|* Software is furnished to do so, subject to the following        *|
|* conditions.                                                     *|
|* --------------------------------------------------------------- *|
|* The above copyright notice and this permission notice shall be  *|
|* included in all copies or substantial portions of the Software. *|
|* --------------------------------------------------------------- *|
|* THE SOFTWARE IS PROVIDED "AS IS", WITHOUT WARRANTY OF ANY KIND, *|
|* EXPRESS OR IMPLIED, INCLUDING BUT NOT LIMITED TO THE WARRANTIES *|
|* OF MERCHANTABILITY, FITNESS FOR A PARTICULAR PURPOSE AND        *|
|* NONINFRINGEMENT. IN NO EVENT SHALL THE AUTHORS OR COPYRIGHT     *|
|* HOLDERS BE LIABLE FOR ANY CLAIM, DAMAGES OR OTHER LIABILITY,    *|
|* WHETHER IN AN ACTION OF CONTRACT, TORT OR OTHERWISE, RISING     *|
|* FROM, OUT OF OR IN CONNECTION WITH THE SOFTWARE OR THE USE OR   *|
|* OTHER DEALINGS IN THE SOFTWARE.                                 *|
\*******************************************************************/

/**********************\
|* REQUIRED LIBRARIES *|
\**********************/

#include <xc.h>

/********************\
|* DEVICE CONSTANTS *|
\********************/

/**
 * Frequency of the internal oscillator.
 */

#define _XTAL_FREQ 4000000

/**
 * Period of the PWM signal. Period of <i>1000</i> will
 * be equal to <i>1000</i> instruction cycles, each one
 * executed every <i>FOSC/4</i> HZ.
 * 
 * Note: Period of <i>1000</i> is equal to <i>1s</i> when
 * internal oscillator is set to <i>4 MHz</i>.
 */

#define _PWM_PERIOD 500

/**
 * Period within which status indicator may blink.
 */

#define _STS_PERIOD 3000

/**
 * Maximum current that the charger can supply to the battery,
 * expressed in <i>mA</i>.
 */

#define _CHG_CURRENT 350

/*********************\
|* BATTERY CONSTANTS *|
\*********************/

/**
 * Capacity of the connected battery in <i>mAh</i> used in
 * the control loop for preventing overcharing.
 */

#define _BAT_CAPACITY 3000

/*********************\
|* BATTERY CONSTANTS *|
\*********************/

/**
 * Code used for indicating that the NTC thermistor
 * is either not connected or failed.
 */

#define _CD_THERM_FAIL 4

/**
 * Code used for indicating that the temperature is
 * too high to safely charge the battery.
 */

#define _CD_TEMP_HIGH 4

/**
 * Code used for indicating that the temperature is
 * too low to safely charge the battery.
 */

#define _CD_TEMP_LOW 3

/**
 * Code used for indicating that the battery
 * is  being charged.
 */

#define _CD_CHARGING 2

/**********************\
|* CONFIGURATION BITS *|
\**********************/

/**
 * Note: Additional details can be found in the following file:
 *   - xc8\v2.31\docs\chips\16f687.html
 */

#pragma config FOSC = INTRCIO

#pragma config WDTE = OFF

#pragma config PWRTE = OFF

#pragma config MCLRE = OFF

#pragma config CP = OFF

#pragma config CPD = OFF

#pragma config BOREN = OFF

#pragma config IESO = OFF

#pragma config FCMEN = OFF

/*****************\
|* PWM VARIABLES *|
\*****************/

/**
 * Last analog conversion of the temperature probe.
 */

int ADC_TEMP = 0x0;

/**
 * Last analog conversion of the reference voltage.
 */

int ADC_REF = 0x0;

/*****************\
|* PWM VARIABLES *|
\*****************/

/**
 * Temporary variable used to track the number of instruction
 * cycles for PWM management when PWM output is enabled.
 */

volatile unsigned int PWM_TICKS = 0;

/**
 * Flag used for toggling the PWM signal.
 */

__bit PWM_ENABLED = 0;

/**
 * Number of instruction cycles that the PWM signal
 * should remain in the HIGH state.
 */

unsigned int PWM_ON = 0;

/**
 * Number of instruction cycles that the PWM signal
 * should remain in the LOW state.
 */

unsigned int PWM_OFF = 0;

/**************\
|* INTERRUPTS *|
\**************/

/**
 * Interrupt procedure for timer <i>0</i> used for
 * generating a PWM for battery charging.
 * 
 * @author    Djordje Jocic <office@djordjejocic.com>
 * @copyright 2021 All Rights Reserved
 * @version   1.0.0
 * 
 * @return void
 */

void __interrupt() pwm_routine(void) {
    
    // Logic
    
    if (T0IF) {
        
        if (PWM_ENABLED) {
            
            if (RB4 == 0x0 && PWM_TICKS >= PWM_OFF) {
                RB4       = 0x1;
                PWM_TICKS = 0x0;
            }
            else if (RB4 == 0x1 && PWM_TICKS >= PWM_ON) {
                RB4       = 0x0;
                PWM_TICKS = 0x0;
            }
            
            PWM_TICKS ++;
        }
        else {
            RB4 = 0x0;
        }
        
        T0IF = 0x0;
    }
}

/*************\
|* FUNCTIONS *|
\*************/

/**
 * Appropriately configures the microcontroller.
 * 
 * @author    Djordje Jocic <office@djordjejocic.com>
 * @copyright 2021 All Rights Reserved
 * @version   1.0.0
 * 
 * @return void
 */

void setup(void) {
    
    // Internal Oscillator
    
    IRCF0 = 0x1;
    IRCF1 = 0x1;
    IRCF2 = 0x1;
    OSTS  = 0x0;
    HTS   = 0x1;
    LTS   = 0x1;
    SCS   = 0x1;
    
    // General Configuration
    
    OPTION_REG = 0x80;
    C1ON       = 0x0;
    C2ON       = 0x0;
    
    // Interrupts
    
    GIE   = 0x1;
    PEIE  = 0x1;
    T0IE  = 0x1;
    INTE  = 0x0;
    RABIE = 0x0;
    ADIE  = 0x0;
    
    // Timers
    
    T0CS = 0x0;
    PS2  = 0x0;
    PS1  = 0x1;
    PS0  = 0x0;
    
    // Analog Ports
    
    ADFM   = 0x1;
    VCFG   = 0x0;
    ADON   = 0x0;
    ADCS2  = 0x0;
    ADCS1  = 0x1;
    ADCS0  = 0x1;
    ANSEL  = 0xC;
    ANSELH = 0x0;
    
    // Digital Ports
    
    TRISA5 = 0x1;
    TRISB4 = 0x0;
    TRISC0 = 0x0;
}

/**
 * Sets the duty cycle of the PWM signal.
 * 
 * @author    Djordje Jocic <office@djordjejocic.com>
 * @copyright 2021 All Rights Reserved
 * @version   1.0.0
 * 
 * @param unsigned char cycle
 *   Duty cycle of the PWM signal, ex. <i>50</i>.
 * @return void
 */

void set_pwm_cycle(unsigned char cycle) {
    
    // Logic
    
    PWM_TICKS = 0x0;
    PWM_ON    = ((cycle * _PWM_PERIOD) / 100);
    PWM_OFF   = _PWM_PERIOD - PWM_ON;
    
}

/**
 * Enables or disables the PWM signal.
 * 
 * @author    Djordje Jocic <office@djordjejocic.com>
 * @copyright 2021 All Rights Reserved
 * @version   1.0.0
 * 
 * @param unsigned char enabled
 *   Value <i>1</i> or <i>0</i> to enable/disable the
 *   PWM signal respectively.
 * @return void
 */

void set_pwm_enabled(unsigned char enabled) {
    
    // Logic
    
    PWM_ENABLED = (enabled & 0x1);
    PWM_TICKS   = 0x0;
    
    if (PWM_ON == 0x0 && PWM_OFF == 0x0) {
        set_pwm_cycle(50);
    }
    
    RB4 = (enabled & 0x1);
}

/**
 * Calculates the required PWM cycle for a given charge.
 * 
 * @author    Djordje Jocic <office@djordjejocic.com>
 * @copyright 2021 All Rights Reserved
 * @version   1.0.0
 * 
 * @param unsigned char charge
 *   Charge of the battery, ex. <i>20</i> for <i>0.2C</i>.
 * @return void
 */

unsigned char calc_cycle(unsigned char charge) {
    
    // Core Variables
    
    unsigned int current = _CHG_CURRENT;
    
    // Logic
    
    if (_CHG_CURRENT > _BAT_CAPACITY) {
        current = _BAT_CAPACITY;
    }
    
    return (unsigned char)((100 * (current * (charge / 100))) / current);
}

/**
 * Flashes an indicator <i>n</i> times.
 * 
 * @author    Djordje Jocic <office@djordjejocic.com>
 * @copyright 2021 All Rights Reserved
 * @version   1.0.0
 * 
 * @param unsigned char n
 *   Number of times that the indicator should be flashed.
 * @return void
 */

void blink(unsigned char n) {
    
    // Core Variables
    
    unsigned int  i     = 0;
    unsigned char delay = (unsigned char)(_STS_PERIOD / n);
    
    // Logic
    
    while (n --) {
        
        RC0 = 0x1;
        
        for (i = 0; i < delay; i++) {
            __delay_ms(1);

        }

        RC0 = 0x0;
        
        for (i = 0; i < delay; i++) {
            __delay_ms(1);
        }
    }
}

/**
 * Performs A/D conversion procedure for the temperature.
 * 
 * Correlation between temperature and voltage:
 *   - 5C  => 1.47V
 *   - 45C => 3.33V
 * 
 * @author    Djordje Jocic <office@djordjejocic.com>
 * @copyright 2021 All Rights Reserved
 * @version   1.0.0
 * 
 * @return void
 */

void probe_temp() {
    
    // Logic
    
    CHS3 = 0x0;
    CHS2 = 0x0;
    CHS1 = 0x1;
    CHS0 = 0x1;
    
    ADON = 0x1;
    
    __delay_ms(30);
    
    GO = 0x1;
    
    while (!GO) {
        __delay_us(10);
    } 
            
    ADC_TEMP = (ADRESH << 8) | ADRESL;
}

/**
 * Performs A/D conversion procedure for the battery voltage.
 * 
 * @author    Djordje Jocic <office@djordjejocic.com>
 * @copyright 2021 All Rights Reserved
 * @version   1.0.0
 * 
 * @return void
 */

void probe_bat() {
    
    // Logic
    
    CHS3 = 0x0;
    CHS2 = 0x0;
    CHS1 = 0x1;
    CHS0 = 0x0;
    
    ADON = 0x1;
    
    __delay_ms(30);
    
    GO = 0x1;
    
    while (!GO) {
        __delay_us(10);
    } 
            
    ADC_REF = (ADRESH << 8) | ADRESL;
}

/**
 * Reads available 8-bit value from the specified EEPROM address.
 * 
 * @author    Djordje Jocic <office@djordjejocic.com>
 * @copyright 2021 All Rights Reserved
 * @version   1.0.0
 * 
 * @param unsigned char address
 *   Address that should be used during the procedure.
 * @return unsigned char
 *   8-bit value from the address.
 */

unsigned char read_data(unsigned char address)
{
    // Logic
    
    GIE    = 0x0;
    EEADR  = address;
    EECON1 = 0x1;
    RD     = 0x1;

    while (RD == 0x1) {
        __delay_us(10);
    }
    
    GIE = 0x1;
    
    return EEDAT;
}

/**
 * Writes an arbitrary 8-bit value to the specified EEPROM address.
 * 
 * @author    Djordje Jocic <office@djordjejocic.com>
 * @copyright 2021 All Rights Reserved
 * @version   1.0.0
 * 
 * @param unsigned char address
 *   Address that should be used during the procedure.
 * @param unsigned char value
 *   8-bit value that should be written.
 * @return unsigned char
 *   Value <i>0</i> if procedure was successful, and vice versa.
 */

unsigned char write_data(unsigned char address, unsigned char value)
{
    // Logic
    
    while (WR == 0x1) // Wait For Last Write Procedure
    {
        __delay_us(10);
    }
    
    EEADR  = address;
    EEDAT  = value;
    GIE    = 0x0;
    WREN   = 0x1;
    EECON2 = 0x55; // Mandatory Step During The Write Procedure
    EECON2 = 0xAA; // Mandatory Step During The Write Procedure
    WR     = 0x1;
    WREN   = 0x0;
    GIE    = 0x1;
    
    return WRERR;
}

/**
 * Checks whether the charging was shutdown by the
 * external security measure to prevent overcharging.
 * 
 * @author    Djordje Jocic <office@djordjejocic.com>
 * @copyright 2021 All Rights Reserved
 * @version   1.0.0
 * 
 * @return __bit
 *   Value <i>1</i> if charging was shutdown, and vice versa.
 */

__bit is_shutdown() {
    
    // Logic
    
    if (PWM_ENABLED == 0x1) {
        
        while (RB4 == 0x0) {
            __delay_us(10);
        }
        
        return RB5 == 0x0;
        
    }
    
    return 0x0;
}

/**
 * Generic main method for the charger.
 * 
 * @author    Djordje Jocic <office@djordjejocic.com>
 * @copyright 2021 All Rights Reserved
 * @version   1.0.0
 * 
 * @return void
 */

void main(void) {
    
    // Core Variables
    
    unsigned char cycle = read_data(0x0);
    
    // Logic
    
    __delay_ms(1000);
    
    setup();
    
    while (0x1) {
        
        // Disable PWM & Reset PWM Cycle
        
        set_pwm_enabled(0x0);
        set_pwm_cycle(0x0);
        
        // Probe Temperature & Enable PWM If It's Safe
        
        probe_temp();
        
        if (ADC_TEMP == 1023) {
            blink(_CD_THERM_FAIL);
        }
        else if (ADC_TEMP < 305) {
            blink(_CD_TEMP_LOW);
        }
        else if (ADC_TEMP > 680) {
            blink(_CD_TEMP_HIGH);
        }
        else {
            set_pwm_enabled(0x1);
        }
        
        // PWM Management
        
        if (PWM_ENABLED) {
            
            // Probe Battery
            
            RB4 = 0x1;

            probe_bat();

            RB4 = 0x0;
            
            // Process ADC Conversion
            
            if (ADC_REF > 285) { // Pre-Conditioning Stage
                set_pwm_cycle(calc_cycle(20));
            }
            else if (ADC_REF > 45) { // Constant Current Stage
                set_pwm_cycle(calc_cycle(80));
            }
            else if (ADC_REF > 20) { // Constant Voltage Stage
                
                if (cycle == 0xFF) {
                    cycle = calc_cycle(80);
                }
                
                while (cycle --) {
                    
                    set_pwm_cycle(cycle);
                    
                    write_data(0x0, cycle);
                    
                }
            }
        }
        
        // Charging Indicator
        
        if (cycle != 0x0 || is_shutdown()) {
            blink(_CD_CHARGING);
        }
    }
}

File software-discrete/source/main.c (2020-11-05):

/*******************************************************************\
|* Author: Djordje Jocic                                           *|
|* Year: 2020                                                      *|
|* License: MIT License (MIT)                                      *|
|* =============================================================== *|
|* Personal Website: http://www.djordjejocic.com/                  *|
|* =============================================================== *|
|* Permission is hereby granted, free of charge, to any person     *|
|* obtaining a copy of this software and associated documentation  *|
|* files (the "Software"), to deal in the Software without         *|
|* restriction, including without limitation the rights to use,    *|
|* copy, modify, merge, publish, distribute, sublicense, and/or    *|
|* sell copies of the Software, and to permit persons to whom the  *|
|* Software is furnished to do so, subject to the following        *|
|* conditions.                                                     *|
|* --------------------------------------------------------------- *|
|* The above copyright notice and this permission notice shall be  *|

|* included in all copies or substantial portions of the Software. *|
|* --------------------------------------------------------------- *|
|* THE SOFTWARE IS PROVIDED "AS IS", WITHOUT WARRANTY OF ANY KIND, *|
|* EXPRESS OR IMPLIED, INCLUDING BUT NOT LIMITED TO THE WARRANTIES *|
|* OF MERCHANTABILITY, FITNESS FOR A PARTICULAR PURPOSE AND        *|
|* NONINFRINGEMENT. IN NO EVENT SHALL THE AUTHORS OR COPYRIGHT     *|
|* HOLDERS BE LIABLE FOR ANY CLAIM, DAMAGES OR OTHER LIABILITY,    *|
|* WHETHER IN AN ACTION OF CONTRACT, TORT OR OTHERWISE, RISING     *|
|* FROM, OUT OF OR IN CONNECTION WITH THE SOFTWARE OR THE USE OR   *|
|* OTHER DEALINGS IN THE SOFTWARE.                                 *|
\*******************************************************************/

/**********************\
|* REQUIRED LIBRARIES *|
\**********************/

#include <xc.h>

/**************************\
|* MCU CONFIGURATION BITS *|
\**************************/

/**
 * Oscillator Selection Bits: Internal oscillator selection,
 * and I/O functions on GP4 & GP5 pins.
 */

#pragma config FOSC = INTRCIO

/**
 * Watchdog Timer Enable Bit: Disabled because of
 * the project requirements.
 */

#pragma config WDTE = OFF

/**
 * GP3/MCLR Pin Function Select: Disabled because of the project
 * requirements. MCLR is internally tied to the VDD and GP3 is
 * freed for I/O functions.
 */

#pragma config MCLRE = OFF

/**
 * Power-Up Timer Enable Bit Disabled because of
 * the project requirements.
 */

#pragma config PWRTE = OFF

/**
 * Brown-Out Detect Enable Bit: Enabled to prevent potential
 * damage to the MCU if power-supply fails.
 */

#pragma config BOREN = ON

/**
 * Code Protection Bit: Disabled for obvious reasons.
 */

#pragma config CP = OFF

/**
 * Data Code Protection Bit: Disabled for obvious reasons.
 */

#pragma config CPD = OFF

/******************\
|* CORE CONSTANTS *|
\******************/

/**
 * Internal oscillator constant used for timing-related
 * functions within the XC library.
 * 
 * @type integer
 */

#define _XTAL_FREQ 4000000

/**
 * Debug flag. Alternative constants will be used when/if set.
 * 
 * @type integer
 */

#define DEBUG 0

/**
 * Delay in milliseconds between the status intervals.
 * 
 * @type integer
 */

#define STS_TIMEOUT 2000

/**
 * Delay in milliseconds between the status "blinks."
 * 
 * @type integer
 */

#define STS_DELAY 200

/*********************\
|* BATTERY CONSTANTS *|
\*********************/

/**
 * Voltage threshold up to which the battery will be considered
 * dead, or disconnected.
 * 
 * Threshold: 1.00
 * 
 * @type integer
 */

#define DEAD_VOLTAGE 80

/**
 * Voltage threshold up to which the CCCV (S1) charging
 * current will be used.
 * 
 * Threshold: 5.25
 * 
 * @type integer
 */

#define CCCV_VOLTAGE 820

/**
 * Number of LED "blinks" that will be used to indicate
 * CCCV (S1) charging.
 */

#define CCCV_INDICATOR 1

/**
 * Voltage threshold up to which the TOPPING (S2) charging
 * current will be used.
 * 
 * Threshold: 6.50
 * 
 * @type integer
 */

#define TOPPING_VOLTAGE 990

/**
 * Number of LED "blinks" that will be used to indicate
 * TOPPING (S2) charging.
 */

#define TOPPING_INDICATOR 2

/**
 * Voltage threshold up to which the FLOAT (S3) charging
 * current will be used.
 * 
 * Threshold: 6.75
 * 
 * @type integer
 */

#define FLOAT_VOLTAGE 1020

/**
 * Number of LED "blinks" that will be used to indicate
 * FLOAT (S3) charging.
 */

#define FLOAT_INDICATOR 3

/**
 * Number of LED "blinks" that will be used to indicate
 * that there is a dead batter connected, or that there
 * is no battery at all.
 */

#define DEAD_INDICATOR 4

/*********************\
|* BATTERY CONSTANTS *|
\*********************/

/**
 * Voltage of the battery that is being charged is monitored in
 * intervals. Length of that interval in milliseconds.
 */

#define MONITOR_INTERVAL 3000

/**
 * Number of milliseconds that the battery charging will be
 * paused after the threshold of the <i>FLOAT</i> voltage
 * has been reached/passed.
 */

#define CHARGING_TIMEOUT 4500

/******************\
|* CORE VARIABLES *|
\******************/

/**
 * Last ADC value ranging from 0 to 1024.
 * 
 * @type unsigned int
 */

 int conversion = 0x00;

/**
 * Current number of "blinks" of an indicator.
 * 
 * @type unsigned char
 */

unsigned char indicator = 0x00;

/**
 * IO stack containing L/H data that is pushed each cycle.
 * 
 * @type unsigned volatile int
 */

unsigned volatile int io_stack = 0x00;

/*******************\
|* OTHER VARIABLES *|
\*******************/

/**
 * Temporary variables for program's loops.
 * 
 * @type unsigned int
 */

unsigned int i = 0x00, j = 0x00;

/*****************\
|* GET FUNCTIONS *|
\*****************/

// GET FUNCTIONS GO HERE

/*****************\
|* SET FUNCTIONS *|
\*****************/

// SET FUNCTIONS GO HERE

/******************\
|* CORE FUNCTIONS *|
\******************/

/**
 * Generic main method for the <i>discrete</i> variant of the
 * <i>HMA</i> project powered by the <i>4 Ah</i> battery.
 * 
 * @author    Djordje Jocic <office@djordjejocic.com>
 * @copyright 2019 All Rights Reserved
 * @version   1.0.0
 * 
 * @return void
 */
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

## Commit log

2020-08-23 USB Connection & ESD Protection.
    [hardware.kicad_pcb, hardware.sch]
2020-08-23 3.3V Voltage Regulator.
    [hardware.sch]
2020-08-24 Battery protection circuit.
    [hardware.sch]
2020-08-24 Battery management circuit.
    [hardware.sch]
2020-08-24 Basic MCU wiring for a test batch.
    [hardware.sch]
2020-08-24 Assigned footprints to the project.
    [hardware.csv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]
2020-08-24 MAX2871 datasheet & footprint.
    [hardware.sch]
2020-08-24 Compacted schematics.
    [hardware.sch]
2020-08-24 50 MHz reference.
    [hardware.sch]
2020-08-24 MAX2871 decoupling.
    [hardware.sch]
2020-09-01 Added CVCO55 footprint, symbol & 3D model.
    [cvco55.step, hardware.kicad_pcb, hardware.sch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]
2020-09-01 Added NLB-310 footprint, symbol & 3D model.
    [hardware.kicad_pcb, micro-x-4.step]
2020-09-02 500-1000 MHz & 1000-2000 MHz Crystek VCOs.
    [hardware.kicad_pcb, hardware.sch, sma-edge.step]
2020-09-03 1600-3200 MHz & 3180-3710 MHz Crystek VCOs.
    [hardware.sch]
2020-09-04 Additional VCOs for 100-500 MHz range.
    [hardware.sch]
2020-09-05 Assigned footprints & part IDs.
    [hardware.sch]
2020-09-05 Added CVCO datasheets.
    [hardware.sch]
2020-09-06 Pover supply for CVCO variant.
    [hardware.sch]
2020-09-06 Battery management for CVCO variant.
    [hardware.sch]
2020-09-06 24V boost circuit added - CVCO.
    [hardware.sch]
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2020-09-19 Added TQFN-32 model.
    [hardware.kicad_pcb, hardware.sch, tqfn-32.step]
2020-09-19 Fixed minor issue with RF Output.
    [hardware.kicad_pcb, hardware.sch]
2020-09-27 VCO switcher.
    [file668398EA.sch, file66B33606.sch, hardware.sch]
2020-09-27 IC buffer added.
    [hardware.sch]
2020-09-27 Noise Source & Summer added.
    [hardware.sch]
2020-09-30 Simplified CVCO design.
    [hardware.kicad_pcb, hardware.sch]
2020-09-30 LCSC part numbers assigned.
    [hardware.kicad_pcb, hardware.sch]
2020-09-30 RF layout - start.
    [hardware.kicad_pcb]
2020-10-02 RF section layout finished - CVCO.
    [hardware.kicad_pcb, hardware.sch]
2020-10-02 Added horizontal Molex footprint & 3D model.
    [2-2.54mm-horizontal-molex.step, hardware.kicad_pcb, hardware.sch]
2020-10-02 Rough layout of the non-RF section.
    [hardware.kicad_pcb, hardware.sch]
2020-10-03 Added icons & icon footprints - CVCO.
    [hardware.kicad_pcb, hardware.sch]
2020-10-03 Replaced FA icons.
    [hardware.kicad_pcb]
2020-10-03 Assigned LCSC parts to battery mng. section.
    [hardware.sch]
2020-10-03 Replaced LM358 with LM324.
    [hardware.kicad_pcb, hardware.sch]
2020-10-03 Non-RF section layout finished - CVCO.
    [hardware.kicad_pcb, hardware.sch]
2020-10-03 RF section routing - CVCO.
    [hardware-B_Cu.gbr, hardware-B_Mask.gbr, hardware-B_SilkS.gbr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]
2020-10-04 Power Supply & Battery Management routing - CVCO.
    [hardware.kicad_pcb, hardware.sch]
2020-10-04 Sweep Generator routing - CVCO.
    [hardware.kicad_pcb, hardware.sch]
2020-10-04 Noise Source routing - CVCO.
    [hardware.kicad_pcb, hardware.sch]
2020-10-05 PIC routing - CVCO.
    [hardware.kicad_pcb, hardware.sch]
2020-10-05 Updated RF section - CVCO.
    [hardware.kicad_pcb]
2020-10-06 Buffer routing - CVCO.
    [hardware.kicad_pcb, hardware.sch]
2020-10-10 RF Section Buffer routing - CVCO.
    [hardware.kicad_pcb, hardware.sch]
2020-10-10 RF shield - CVCO.
    [hardware.kicad_pcb]
2020-10-10 Redone RF shield - CVCO.
    [hardware.kicad_pcb]
2020-10-11 Finalized CVCO variant.
    [hardware.kicad_pcb, hardware.sch]
2020-10-11 BOM & Gerber files - CVCO.
    [bom.csv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]
2020-10-13 200-400 MHz MOSFET VCO - Schema.
    [vco.kicad_pcb, vco.sch]
2020-10-24 Boost circuit update.
    [hardware.kicad_pcb, hardware.sch]
2020-10-24 Boost circuit update - PCB.
    [hardware.kicad_pcb]
2020-10-24 Battery managment, boost & sweep - discrete.
    [hardware-discrete.kicad_pcb, hardware-discrete.sch]
2020-10-30 Power Supply & Battery Management update.
    [hardware-discrete.sch]
2020-10-31 Temperature control.
    [hardware-discrete.sch]
2020-11-01 Battery management software - untested.
    [main.obj, startup.obj]
2020-11-01 Battery management update.
    [hardware-discrete.sch, main.obj]
2020-11-02 Battery management code finalization.
    [main.obj]
2020-11-03 Charging switch.
    [hardware-discrete.sch, main.obj]
2020-11-04 Minor tweaks to battery management.
    [bjt-switches.ods, main.obj]
2020-11-05 Noise source for discrete version.
    [bjt-switches.ods, hardware-discrete.sch, main.obj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]
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2021-01-24 Li-Po charger module - schema.
    [charger.kicad_pcb, cvco.sch, psu.sch]
2021-01-26 Li-Po charger module - PCB.
    [charger.kicad_pcb, charger.sch]
2021-01-26 Gerber files - PSU.
    [2n2222-osc.kicad_pcb, 2n2222-osc.sch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]
2021-01-26 Gerber files - Charger.
    [charger-B_Cu.gbr, charger-B_Mask.gbr, charger-B_SilkS.gbr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]
2021-01-26 Generated BOM for PSU & Charger mod.
    [2n2222-osc.kicad_pcb, 2n2222-osc.sch, cvco.kicad_pcb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]
2021-02-01 RF Amplifier module - ADL.
    [adl-variant-B_Cu.gbr, adl-variant-B_Mask.gbr, adl-variant-B_SilkS.gbr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]
2021-02-01 RF Amplifier module - NLB.
    [bom.csv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]
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2021-02-01 Trans. line width issue resolved - amp. modules.
    [adl-variant-B_Cu.gbr, adl-variant-B_Mask.gbr, adl-variant-B_SilkS.gbr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]
2021-02-07 CVCO 500-1000 MHz module - Schema.
    [500-1000-cvco.kicad_pcb, 500-1000-cvco.sch, design.ods]
2021-02-09 CVCO 500-1000 MHz module - PCB.
    [3-3.84-terminal-block.step, 500-1000-cvco.kicad_pcb, 500-1000-cvco.sch]
2021-02-09 CVCO 500-1000 MHz module - Gerber Files.
    [500-1000-cvco-B_Cu.gbr, 500-1000-cvco-B_Mask.gbr, 500-1000-cvco-B_SilkS.gbr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]
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2021-02-22 Fixed 3D model paths - PSU (linear).
    [linear-variant.kicad_pcb]
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
